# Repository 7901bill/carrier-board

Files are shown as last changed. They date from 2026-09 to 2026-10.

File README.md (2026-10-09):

# Carrier Board — Read This First

## Current PCB finishing work - 2026-10-09

Routing is substantially implemented in the saved PCB: all nine differential
pairs are defined and each member has top-layer tracks. Finish corner GND
vias, revise the board outline, and add/re-pour the required polygon copper.
Then refresh connectivity and resolve remaining DRC items in Altium. Final
routing, impedance, and release sign-off remain open.

The read-only saved-file audit found 85 connection records (83 GND and two
`NetCN1_78`), a broadly scoped 90-ohm differential rule, and unequal USB
track-only lengths. No DRC report was found, so a small remaining violation
count is not independently confirmed. See the [PCB audit](Documentation/PCB-Audit-2026-10-09.md) for evidence
and the limits of this inspection.

See the [current design status](Documentation/documentation.md) and
[subsystem dashboard](Documentation/Schematic-Subsystems/README.md).

## Earlier schematic-review findings requiring final re-verification

Both Amphenol `10164227-1001A1RLF` schematic instances now contain 100 unique
pin designators numbered `1–100`, matching their physical footprint pads.
`CN1` represents CM5 logical pins 1–100 and `CN2` represents logical pins
101–200; the unique component designators distinguish their identical pad
numbers.

The earlier warning that CN1 pins `3–6`, `9–12`, and `15–20` were grounds was
incorrect. Those are Ethernet, fan, LED, sync, and EEPROM-control signals.
Unused signals remain open; only pins identified as GND by the CM5 datasheet
are grounded.

The [current design status](Documentation/documentation.md) records all 43
schematic components in the saved LiveBOM and PCB, with their footprint names
matching. The earlier 2026-09-19 saved-CAD review found
incorrect camera-LDO pin assignments, disconnected Hailo output capacitors,
and USB ground contacts. The camera-LDO mapping remains incorrect in the
2026-09-24 ECO. Recovery switch `SW` has since been added and ECO-connected,
but its physical operation remains unverified. A clean compile is not
electrical sign-off.

At the 2026-09-29 documentation checkpoint, PCB layout setup had an
approximately 100 mm x 60 mm working outline,
all 43 components placed, a four-layer `SIG 1`/`GND`/`PWR`/`SIG 2` stack, and
basic clearance/width/via rules. That review listed open schematic,
mechanical, differential-pair, and net-name checks. Do not assume those older
items are closed merely because routing has started; re-verify affected nets
and rules before final sign-off.

## Documentation workflow

- [`Documentation/Journal.md`](Documentation/Journal.md) is the source of
  truth for verified decisions, evidence, and completed work.
- [`Documentation/documentation.md`](Documentation/documentation.md) is the
  daily progress record, active-blocker list, and resume checkpoint.
- [`Documentation/Schematic-Subsystems/`](Documentation/Schematic-Subsystems/README.md)
  contains the detailed implementation and verification status for each
  schematic block.

Whenever Bill asks to **update the documentation**, synchronize all three
layers in the same documentation pass:

1. Record verified facts and decisions in `Journal.md`.
2. Update the current progress, blockers, reminders, and daily changes in
   `documentation.md`.
3. Update the affected subsystem files and the subsystem progress dashboard.

Resolve contradictory current-status statements during that pass. Preserve
dated history, but clearly mark any older conclusion that a newer verified
entry supersedes.

Do **not** release or fabricate until PCB placement/routing and final DRC,
mechanical, BOM, and CPL reviews are complete.

Review the current design status, project journal, and affected subsystem
records before continuing.

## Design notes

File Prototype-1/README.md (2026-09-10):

# Wireless-Watchdog
Real-time animal spotting with YOLOv8n and at 433 MHz.

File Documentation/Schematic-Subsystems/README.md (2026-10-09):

# Schematic Subsystems

Last updated: 2026-10-09

This folder is the detailed working record for Schematic V1 of the Wireless
Watchdog CM5 carrier board. Each file covers one independently reviewable
subsystem. `Documentation/Journal.md` is the source of truth for verified
decisions, while `Documentation/documentation.md` is the daily working summary
and active-blocker list.

## Current PCB finishing work - 2026-10-09

Routing is substantially implemented in the saved PCB: all nine differential
pairs are defined and each member has top-layer tracks. Finish corner GND
vias, revise the board outline, and add/re-pour the required polygon copper.
Then refresh connectivity and resolve remaining DRC items in Altium. Final
routing, impedance, and release sign-off remain open.

The read-only saved-file audit found 85 connection records (83 GND and two
`NetCN1_78`), a broadly scoped 90-ohm differential rule, and unequal USB
track-only lengths. No DRC report was found, so a small remaining violation
count is not independently confirmed. See the [PCB audit](../PCB-Audit-2026-10-09.md) for evidence
and the limits of this inspection.

## Earlier schematic review findings

These are historical findings pending final re-verification, rather than a
new electrical audit. The October 9 PCB audit confirms routing progress but
does not close the earlier electrical or mechanical review items.

Schematic V1 completion is reopened. PCB import and a clean compile were
reported, but the saved-CAD review found electrical omissions and incorrect
LDO pin mapping. Re-verify affected items before release. The
[current design status](../documentation.md) contains the consolidated open
findings; the subsystem records below contain the supporting implementation
details.

## Progress dashboard

| File | Subsystem | Draft status | Principal remaining work |
|---|---|---|---|
| [01](01-power-input-usb-pd.md) | USB-C power input and PD | Validation open | Source/fuse budget; proposed Basic R1 |
| [02](02-main-5v-power.md) | Main 5 V supply | Validation open; placed | Reconcile main-rail/plane name; verify routed converter loop; peak-power review |
| [03](03-hailo-power-sequencing.md) | Hailo power and sequencing | Correction required; placed | Recheck C8/C9; verify routed buck loop; validate reset timing |
| [04](04-camera-power.md) | Camera power | Critical correction | Fix U3 pin mapping; add output capacitor; thermal review |
| [05](05-cm5-connectors.md) | CM5 connectors | **Component/footprint verified; placed; routing substantially implemented** | Preserve verified 10164227-1001A1RLF parts; finish board-level alignment, access, and fit checks |
| [06](06-m2-hailo-pcie.md) | M.2 Hailo/PCIe | **High priority release blocker; placed** | Resolve CN3 identity; verify three routed pairs and rule/profile scopes |
| [07](07-csi2-camera.md) | CSI-2 camera | Power dependency open; placed | Correct camera supply; verify FPC orientation; verify five routed pairs and 100-ohm rule scope |
| [08](08-programming-usb.md) | Programming USB | Correction required; placed | Recheck grounds; add ESD; verify routed USB pair, rule scope, and skew; review VBUS |
| [09](09-boot-recovery-reset.md) | Boot and recovery | SW placed and ECO-connected | Validate footprint and test point; accessible placement/routing; recovery test |
| [10](10-debug-uart.md) | Debug UART | Schematic complete | Place accessible connector and label pin order |
| [11](11-status-test-points.md) | Status and test access | Rough draft | Select final indicators and test points |

## Locked high-speed routing requirements

The current official CM5 datasheet establishes two controlled-impedance
classes for the nine routed differential pairs:

- 90 ohms differential: PCIe TX, PCIe RX, PCIe reference clock, and
  programming USB 2.0 D+/D-.
- 100 ohms differential: MIPI0 data lanes 0-3 and MIPI0 clock.

The earlier 85-ohm PCIe project note is superseded. Actual widths and gaps
have reportedly been calculated from the configured stackup, but they still
require JLCPCB confirmation. The October 9 audit confirms all nine pair objects. The highest-priority
`USB_DiffPair` rule is profile-driven at 90 ohms but scoped to `All`; confirm
and correct its effective scope, particularly for the 100-ohm MIPI pairs.
The lower-priority generic rule remains a placeholder.

## Historical PCB layout setup

The bullets below record the September setup. The current saved plane net
assignments are GND and `5V`; see the October 9 audit for current evidence.

- Working outline: approximately 100 mm x 60 mm; all 43 components are placed
  top-side and inside it. Mechanical fit and connector/retention checks remain.
- Stack: L1 `SIG 1`, L2 solid `GND`, L3 `PWR` intended as the main 5 V plane,
  and L4 `SIG 2`.
- General rules: 0.15 mm clearance, 0.20 mm minimum/0.25 mm preferred width,
  and 0.60 mm/0.30 mm through vias. Resolve the external note's 1.0 mm maximum
  versus the saved rule's 0.50 mm maximum.
- Keep CSI, PCIe, and USB on L1 over continuous L2 ground where practical.
  Avoid L4 for these pairs because its adjacent reference is the power plane.
- The reported PCB rail rename to `5V` is not present in the current saved net
  table, which still uses `NetC2_1`; reconcile it with schematic/documentation
  names before the next ECO.

## Working order

1. Add corner GND vias and revise the board shape.
2. Add/re-pour polygon copper and review ground continuity and islands.
3. Refresh connectivity; inspect saved GND and `NetCN1_78` connections.
4. Verify differential profile/rule scopes and USB length/skew.
5. Resolve remaining DRC items and run final DRC after all layout changes.
6. Re-verify historical electrical/mechanical findings and complete final
   silkscreen, ERC/ECO, BOM/CPL, fabrication, and drill-output reviews.

## Status vocabulary

- **Confirmed:** explicitly locked in the current project documentation.
- **Planned:** required work whose exact implementation may still need review.
- **Open:** requires a design choice or external verification.
- **Done:** implemented in CAD and subsequently verified.

## Session rule

After work on a subsystem, update its status, completed work, open questions,
and session notes. Record verified material decisions in
`Documentation/Journal.md` and keep the active summary in
`Documentation/documentation.md` synchronized.

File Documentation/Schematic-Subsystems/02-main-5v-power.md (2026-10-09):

# 02 — Main 5 V Power Supply

Last updated: 2026-10-09

## Saved PCB checkpoint - 2026-10-09

The saved October 8 PCB independently confirms substantial routing and all
nine differential-pair definitions, superseding the earlier no-pair/no-routing
snapshot below. Finish corner GND vias, the board outline, polygon pours,
connectivity checks, and final DRC. Differential-rule scope and USB skew need
review. This checkpoint does not close older electrical or mechanical findings.
See the [PCB audit](../PCB-Audit-2026-10-09.md) for current evidence.

## Open review actions — 2026-09-19

- Open: the 6.5 A converter rating is not the available system budget.
  A 5 V/6.5 A load is 32.5 W, exceeding the 27 W input before losses.
  Close peak/continuous load and fuse/thermal margins with subsystem 01.
- Proposed only: C4 `C466768` → Basic `C14663` (already C3/C7):
  100 nF, X7R, ±10%, 0603; voltage rating increases from 25 V to 50 V.
- Optional clarity improvement: label main 5 V (`NetC2_1`), Hailo output
  (`NetC11_2`) and camera output (`NetCN4_22`) with their intended rail names.

These actions are not implemented. Current release blockers are consolidated
in the [main design status](../documentation.md).

## Subsystem purpose

Convert the negotiated 9 V input into the shared `5V_MAIN` rail used by the
CM5 and the local Hailo and camera regulators.

## Earlier status snapshot

**Schematic complete and transferred to PCB.** The converter and target rail
are confirmed. Peak-load, transient, efficiency, and thermal verification
remain prototype-validation tasks.

**Historical PCB layout setup:** U5 and its passives are placed. The layout note reports
that L3 is a continuous main-5-V plane and that the PCB net was renamed to
`5V`, but the current saved PCB net table still shows `NetC2_1`; the schematic
and documentation use `5V_MAIN`/`5V_6.5A`. Verify the actual L3 assignment and
choose an ECO-stable authoritative rail name before routing. Route the MP2329
input capacitors, switching loop, inductor, output capacitors, and feedback
network before ordinary signals. The configured generic width rule is not a
power-current rule; derive suitable copper widths/plane connections from the
final current and thermal budget.

## Confirmed design

- Converter: MPS `MP2329GG-Z`, LCSC `C5349327`.
- Input: negotiated 9 V from the USB-PD input section.
- Output: `5V_MAIN`.
- The device is rated for 6.5 A continuous and 7.5 A peak, subject to the
  complete design and thermal conditions.
- Recorded datasheet starting values for 5 V are:
  - upper feedback resistor: 40.2 kΩ, `C12447`;
  - lower feedback resistor: 5.49 kΩ, `C54102278`;
  - feed-forward capacitor: 33 pF, `C48543706`;
  - inductor: 3.3 µH, `C19268654` (`CYA1250-3.3UH`, 20 A rated,
    32 A saturation). This stocked replacement supersedes `C19268642`.
- The CAD sheet also uses 22 µF/25 V capacitors `C45783`, 220 nF/25 V
  capacitor `C21120`, and 100 nF/25 V capacitor `C466768` in the power section.
- MP2329 input qualification is implemented with 453 kΩ `C25818` and 100 kΩ
  `C25803`, targeting an approximately 7.5 V startup threshold.
- `5V_MAIN` directly supplies the CM5 and feeds separate local regulators for
  the Hailo and camera rails.

## Confirmed load facts

- The earlier approximately 13 W system estimate is based mainly on typical
  loading and is not sufficient by itself for final component ratings.
- The Hailo-8L alone can require as much as 6.6 W/2 A at 3.3 V.
- Final verification must consider simultaneous peak load, startup, conversion
  loss, thermal derating, charger capability, and cable capability.

## Planned schematic content

- Complete MP2329 reference circuit.
- Input/output ceramic capacitors with voltage and effective-capacitance margin.
- Feedback and feed-forward network.
- Inductor with suitable RMS and saturation-current ratings.
- Enable and startup behavior coordinated with the USB-PD section.
- `5V_MAIN`, input, switch-node, and ground test access where safe.
- Clear net connections to the CM5 and both local 3.3 V branches.

## Definition of done

- All component values are checked against the current MP2329 datasheet.
- A defensible worst-case power budget is recorded.
- Inductor and capacitors meet electrical and thermal margins.
- The expected startup state is defined for 5 V input and successful 9 V PD.
- Every CM5 5 V input is supplied as required by the CM5 reference design.

## References

- `Documentation/documentation.md`, Power architecture.
- `Documentation/Research MD/power-design-explainer.md`.
- MP2329 datasheet in `Documentation/Datasheets/`.

## Session notes

- 2026-09-18: Initial subsystem draft created from confirmed project records.
- 2026-09-19: Replaced unavailable `C19268642` with stocked `C19268654` and
  imported its dedicated footprint into the PCB project.
- 2026-09-28: Recorded that placement and the four-layer layout setup are
  complete, but the reported `5V` plane/net rename is not reflected in the
  current saved net table. Main-converter loop routing is the first routing
  priority after the open schematic corrections and net/plane verification.

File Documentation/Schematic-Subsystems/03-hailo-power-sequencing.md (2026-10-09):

# 03 — Hailo Power and Reset Sequencing

Last updated: 2026-10-09

## Saved PCB checkpoint - 2026-10-09

The saved October 8 PCB independently confirms substantial routing and all
nine differential-pair definitions, superseding the earlier no-pair/no-routing
snapshot below. Finish corner GND vias, the board outline, polygon pours,
connectivity checks, and final DRC. Differential-rule scope and USB skew need
review. This checkpoint does not close older electrical or mechanical findings.
See the [PCB audit](../PCB-Audit-2026-10-09.md) for current evidence.

## Purpose

Generate the dedicated Hailo-8L 3.3 V rail and ensure that the module remains
in reset until its supply is stable.

## Earlier status snapshot

**Correction required.** The Hailo rail reaches all five M.2 power contacts,
but C8-1 and C9-1 have no PCB net; only their ground pads are connected.
Connect their electrical pin ends to the output (`NetC11_2`), regenerate ECO,
and verify both pads explicitly. Check capacitor tolerance/DC-bias losses.
The TPS54302 is now `U1` (formerly `U3`); its EN pin 5 may float per TI, so
that is not an error. The [main design status](../documentation.md) tracks the
remaining release checks.
Earlier completion notes are superseded; no correction has yet been applied.
The 2026-09-28 inventory audit did not recheck the C8/C9 pad nets, so verify
their current state directly in Altium before closing this item.

## Confirmed design

- Regulator: TI `TPS54302DDCR`, LCSC `C311983`.
- Input: `5V_MAIN`.
- Output: `3V3_HAILO`.
- The Hailo-8L maximum documented load is 2 A at 3.3 V/6.6 W.
- Raw 5 V must never be connected to the Hailo M.2 power contacts.
- The Hailo rail is separate from the camera 3.3 V rail.
- The TPS54302 is an adjustable 3 A, 400 kHz synchronous buck with internal
  soft-start but no power-good output.
- Datasheet starting values recorded by the project are:
  - 100 kΩ from output to FB;
  - 22.1 kΩ from FB to ground;
  - 47 pF across the upper feedback resistor;
  - 6.8 µH inductor;
  - at least 10 µF ceramic input decoupling;
  - 0.1 µF from BOOT to SW;
  - 44 µF effective ceramic output capacitance.
- The inductor must support at least 3 A RMS and preferably more than 4 A
  saturation current.
- Final selected passives are:
  - 6.8 µH molded inductor `C7461350`, 3.5 A rated and 5 A saturation;
  - 100 kΩ upper feedback resistor `C25803`;
  - 22.1 kΩ lower feedback resistor `C723484`;
  - 47 pF C0G feed-forward capacitor `C1671`;
  - two 22 µF output capacitors `C45783`;
  - 100 nF bootstrap capacitor `C14663`.
- `3V3_HAILO` must be stable before M.2 `PERST#` is released.

## Implemented content and open correction

- TPS54302 and selected passives are placed, but output capacitors C8/C9
  require connection before the supply can be considered complete.
- Regulator enable and CM5-controlled reset connections; no separate load
  switch.
- Connection to all five M.2 power contacts.
- After C8/C9 and the rail-net state are corrected and ECO-verified, route the
  TPS54302 input/boot/switch/inductor/output loops and local decoupling before
  ordinary signals. Keep the switch node and inductor away from the PCIe pairs.

## Verification remaining

- Confirm useful test access for `5V_MAIN`, `3V3_HAILO`, reset, and ground.
- Review direct CN2-9 to CN3-50 PERST# behavior with no supply-good gating;
  establish startup and brownout/restart timing before closing sequencing.
- Compile and run ERC after the remaining schematic subsystems are complete.
- Measure startup and confirm `PCIe_nRST` remains asserted until
  `3V3_HAILO` is stable.
- Verify ripple, load transient response, inductor temperature, and effective
  ceramic capacitance on the prototype.

## Load-switch decision

- **Omitted from Rev A:** `TPS22965`, LCSC `C347592`.
- TPS22965 is a load switch, not a step-down regulator. It would only add
  independent rail isolation, slew control, or power cycling.
- `TPS54302DDCR` (`C311983`) remains the required 5 V-to-3.3 V buck regulator.
- Rev A relies on the TPS54302's 5 ms soft-start and the CM5-controlled
  `PCIe_nRST`/M.2 `PERST#` connection. Their relative timing will be measured
  during bring-up.

## Definition of done

- The regulator is fully drawn and configured for 3.3 V.
- All five M.2 power contacts receive `3V3_HAILO`.
- Input/output capacitance is verified at operating bias.
- Inductor current and thermal margins are verified.
- The sequencing circuit provides a documented guarantee that power is stable
  before reset release.
- Enable, reset, and rail behavior can be measured during bring-up.

## References

- `Documentation/Research MD/power-design-explainer.md`.
- `Documentation/Research MD/PCIe-x1-Differential-Pairs-Explainer.md`.
- TPS54302 and Hailo-8L datasheets.

## Session notes

- 2026-09-18: Initial subsystem draft created from confirmed project records.
- 2026-09-19: Completed the sourced TPS54302 circuit and all M.2 power
  connections; reset-timing and prototype validation remain open.
- 2026-09-28: Components are placed and power-loop routing is next, but C8/C9
  must be corrected and verified first. No routing completion is claimed.

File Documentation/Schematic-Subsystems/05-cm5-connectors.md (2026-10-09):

# 05 — CM5 Connectors and Base Connections

Last updated: 2026-10-09

## Saved PCB checkpoint - 2026-10-09

The saved October 8 PCB independently confirms substantial routing and all
nine differential-pair definitions, superseding the earlier no-pair/no-routing
snapshot below. Finish corner GND vias, the board outline, polygon pours,
connectivity checks, and final DRC. Differential-rule scope and USB skew need
review. This checkpoint does not close older electrical or mechanical findings.
See the [PCB audit](../PCB-Audit-2026-10-09.md) for current evidence.

## Purpose

Provide the complete electrical and mechanical interface between the CM5 and
the carrier-board power, PCIe, camera, programming, recovery, and debug
subsystems.

## Earlier status snapshot

**Connector component verified and approved for placement and routing.** `CN1`
and `CN2` use the exact Raspberry Pi-specified Amphenol
`10164227-1001A1RLF` (`C6782225`). Both symbols have 100 unique physical pin
designators `1–100`, and both use the verified manufacturer-matching footprint
`CONN-SMD_100P-P0.40_10164227-1001A1RLF`. No symbol, footprint, or component
replacement is required.

The two placed connector instances are ready to route. Preserve the user's
chosen visible pin names and the verified physical numbering/electrical types.
The 2026-09-23 PCB ECO connects CN1-93 to recovery switch `SW`, which is
grounded on its other terminal. Access, test point, and functional recovery
remain open in [09](09-boot-recovery-reset.md).
Programming USB ground/protection and camera/Hailo supply corrections are
tracked in the [main design status](../documentation.md).
The reported clean compile/ECO does not close those unrelated subsystem
issues. Final board-level CM5 alignment, clearance, and 1:1 assembly fit remain
placement checks, not reasons to change the verified connector component.

## Confirmed design

- The design uses a CM5, not a CM4; their pin assignments are not interchangeable.
- The two carrier connectors are Amphenol `10164227-1001A1RLF` 100-pin parts.
- The exact component identity, schematic pin count, pad numbering, footprint
  association, and copper land geometry were independently verified on
  2026-09-29. The footprint has 100 SMT pads, 0.40 mm pitch, 0.20 mm x 0.70 mm
  lands, 19.60 mm end-to-end contact span, and 3.08 mm row-center spacing,
  matching the Amphenol recommended PCB layout.
- The `-1001A1RLF` variant is the no-hold-down, 1.5 mm mated-stack-height
  receptacle specified for the standard low-profile CM5 installation.
- Connector 1 uses CM5 logical pins 1–100.
- Both schematic symbols and both footprints use physical pin numbers 1–100.
  `CN1` represents CM5 logical pins 1–100; `CN2` represents logical pins
  101–200. Their unique component designators distinguish the two instances.
- CN1 pins 3–6 and 9–12 are Ethernet pairs, not grounds. Pins 15–20 are
  Ethernet/fan/EEPROM-control signals, not grounds. They remain unused in
  Rev A except where later requirements explicitly say otherwise.
- All 21 CN1 ground pins and all 30 CN2 ground pins were checked as connected.
- Unused GPIOs are explicitly disconnected. Pins 51/55 are reserved for UART,
  and pins 97/100 are used for camera control.
- Pins 56/58 (`GPIO3/SCL1`, `GPIO2/SDA1`) are unused; camera control instead
  uses pins 80/82 (`SCL0`, `SDA0`).
- Pins 21 `LED_nACT`, 76 `VBAT`, 92 `PWR_BUT`, 95 `LED_nPWR`, and 99
  `PMIC_ENABLE` are unused in Rev A and have no-connect markers. Pin 93
  `nRPIBOOT` remains reserved for the recovery circuit.
- CM5 pin 78 `GPIO_VREF` connects to the CM5 3.3 V output net from pins 84 and
  86 to select 3.3 V GPIO signaling.
- CM5 pin 55 `GPIO14/UART0_TX` is the debug transmit signal.
- CM5 pin 51 `GPIO15/UART0_RX` is the debug receive signal.
- CM5 pin 93 `nRPIBOOT` is used for USB recovery control.
- CM5 pins 94 and 96 (`CC1` and `CC2`) remain intentionally unconnected in
  this design; neither board USB-C connector uses them.
- CM5 pin 80 `SCL0` and pin 82 `SDA0` are assigned to camera control.
- CM5 pin 97 `CAM_GPIO0` and pin 100 `CAM_GPIO1` are assigned to camera control.
- CM5 MIPI0 mapping is verified as pins 115/117 for data lane 0, 121/123 for
  lane 1, 127/129 for clock, 133/135 for lane 2, and 139/141 for lane 3.
- CM5 pin 141 is `MIPI0_D3_P`; it is not camera lane 0 negative.
- The full CM5 variant has eMMC and does not require a microSD connector.

## Planned schematic content

- Every required CM5 5 V and ground contact.
- Complete PCIe lane, reference clock, reset, and clock-request connections.
- Complete CSI-2, camera I²C, and camera-control connections.
- USB 2.0 programming/recovery signals.
- `nRPIBOOT`, reset/power control, and UART.
- Explicit no-connect markers for every intentionally unused pin.
- Clear cross-sheet net labels with consistent spelling.

## Remaining board-level checks

1. Both connectors are placed; confirm final CM5 mechanical alignment,
   orientation, retention, installed-module clearance, and 1:1 assembly fit.
   This is a placement/system check; the component and footprint are approved.
2. Confirm connector-edge, camera-cable, antenna, heatsink, and access
   constraints within the approximately 100 mm x 60 mm working outline.
3. Re-run PCB DRC after routing and every relevant ECO. Watch for recurrence of
   the stale/corrupt placed-footprint DRC behavior reported during placement.

## Definition of done

- Both connector symbols and footprints are independently verified. Complete
  as of 2026-09-29; do not replace or redraw them without a new approved part.
- Every required power and ground pin is connected.
- Every used interface reaches its corresponding subsystem.
- Every intentionally unused pin has a no-connect marker.
- No CM4 pin assumptions are present.
- A later compile/ECO produces no unexplained connector mismatch.

## References

- Root `README.md` release warning.
- `Documentation/Research MD/CM5-Connector-Wiring-and-Bringup.md`.
- Current CM5 datasheet and official CM5 IO reference design.
- Amphenol connector drawing.

## Session notes

- 2026-09-18: Initial subsystem draft created; connector corrections remain
  the first schematic priority.
- 2026-09-19: Consolidated the connector sheets, connected the complete M.2
  and CSI interfaces, and corrected the imported symbol's displayed camera
  lane labels.
- 2026-09-19: Corrected CN2 to physical pin designators 1–100 and verified both
  placed connectors have 100 unique pins. Confirmed all required grounds are
  grounded and unused GPIOs are disconnected. Corrected the earlier false
  classification of Ethernet/control pins as grounds.
- 2026-09-19: Completed remaining wiring/no-connect treatment, obtained a
  clean compile/ECO with no reported errors or warnings, and transferred all
  components to the PCB document. Component placement is next.
- 2026-09-28: All components, including CN1 and CN2, are placed inside the
  working outline. Placement does not close alignment, retention, clearance,
  footprint, or full mechanical-fit verification.
- 2026-09-29: Closed component and footprint verification for CN1/CN2. Both
  instances are confirmed as Amphenol `10164227-1001A1RLF` / LCSC `C6782225`;
  each symbol has 100 unique pins and each linked footprint matches the
  manufacturer's 100-pad land pattern. No connector-library change is needed.
  The placed instances are approved for routing, subject only to the remaining
  board-level alignment, clearance, and final fit checks above.

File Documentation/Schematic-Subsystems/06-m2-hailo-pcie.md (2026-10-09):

# 06 — Hailo-8L M.2 and PCIe

Last updated: 2026-10-09

## Saved PCB checkpoint - 2026-10-09

The saved October 8 PCB independently confirms substantial routing and all
nine differential-pair definitions, superseding the earlier no-pair/no-routing
snapshot below. Finish corner GND vias, the board outline, polygon pours,
connectivity checks, and final DRC. Differential-rule scope and USB skew need
review. This checkpoint does not close older electrical or mechanical findings.
See the [PCB audit](../PCB-Audit-2026-10-09.md) for current evidence.

## Open review actions — 2026-09-24

- **HIGH PRIORITY - CN3 release blocker. Resolve before PCB fabrication or
  connector procurement.** The selected schematic and BoM DesignItemId is
  UMAX `91302-42-067RDM` (LCSC `C601195`), while the placed PCB footprint
  and embedded STEP model are named for `91302-32-067RDM`. The supplier lists
  the selected `-42-` variant at 4.2 mm and the `-32-` variant at 3.2 mm.
  These are distinct orderable parts. Their name difference does not prove a
  copper land-pattern mismatch, but unverified mating height, locating posts,
  or standoff geometry could prevent the Hailo module from seating and force
  a board rework or respin.
  Compare manufacturer drawings for both variants: contact and mounting pad
  layout, locating posts, board edge, card mating plane, module standoff, and
  nearby clearance. Record the drawing revisions and verified intended part.
  If `-42-` is intended, use or validate a `-42-` footprint and 3D model; if
  `-32-` is intended, correct the schematic part identity and supplier code.
  Refresh the BoM, transfer the change to the PCB, and confirm that CAD and
  purchasing identifiers agree. Do not close this item on matching names alone.
- The latest 2026-09-28 LiveBOM save now agrees with the schematic on CN3's
  Comment, `Name=C601195`, `Source=LCSC`, and selected part. This resolves
  the earlier saved-parameter discrepancy; the `-42-` part versus `-32-`
  footprint/3D mechanical review remains open. See the consolidated
  [main design status](../documentation.md).
- Power dependency: fix disconnected C8/C9 in [03](03-hailo-power-sequencing.md).
  Direct PERST# has no supply-good gating; startup/brownout timing is open.
- Confirm stackup/impedance rules and module mounting before routing.

These actions are not implemented. Current release blockers are consolidated
in the [main design status](../documentation.md).

## Subsystem purpose

Connect the Hailo-8L module to the CM5 over PCIe Gen 2 x1 and provide its
power, clock, reset, and ground connections.

## Earlier status snapshot

**Schematic wiring complete.** The M.2 power, ground, PCIe lane 0, reference
clock, reset, and clock-request signals are connected to the CM5 connector.
Unused lane, wake, configuration, and remaining contacts are intentionally
left unconnected. PCB differential-pair rules, routing, and length tuning
remain layout-phase work.

**Historical PCB layout setup:** CN2 and CN3 are placed, and the configured stack places
L1 over a continuous L2 ground reference. The layout note reports the 90-ohm
profile calculation complete, but the saved PCB still has no PCIe pair objects
or populated PCIe pair class, and its differential routing rule remains the
generic 15 mil/10 mil placeholder. Create the three pair objects, populate the
PCIe class, link its rule to the 90-ohm profile, and verify the geometry with
JLCPCB before routing on L1. The CN3 part/footprint/STEP identity blocker still
must be resolved before placement is considered mechanically final.

## Confirmed parts and architecture

- Socket: UMAX `91302-42-067RDM`, LCSC `C601195`.
- The socket is a 67-contact M-key socket and accepts the Hailo-8L B+M module.
- Link: PCIe Gen 2 x1 from the CM5.
- Only PCIe lane 0 is used; lane 1 receives explicit no-connect markers.
- The M.2 module includes transmit-side AC-coupling capacitors; the carrier
  must not add a duplicate set without a reviewed reason.

## Confirmed power and ground mapping

- `3V3_HAILO`: M.2 pins 2, 4, 70, 72, and 74.
- Ground: pins 3, 27, 33, 39, 45, 51, 57, 71, and 73.
- All listed power and ground contacts must be connected.

## Confirmed PCIe mapping

| M.2 pin/signal | CM5 pin/signal |
|---|---|
| 41 `PETn0` | 118 `PCIe_RX_N` |
| 43 `PETp0` | 116 `PCIe_RX_P` |
| 47 `PERn0` | 124 `PCIe_TX_N` |
| 49 `PERp0` | 122 `PCIe_TX_P` |
| 53 `REFCLKn` | 112 `PCIe_CLK_N` |
| 55 `REFCLKp` | 110 `PCIe_CLK_P` |
| 50 `PERST#` | 109 `PCIe_nRST` |
| 52 `CLKREQ#` | 102 `PCIe_CLK_nREQ` |

The endpoint's transmit signals connect to the host's receive signals, and the
endpoint's receive signals connect to the host's transmit signals.

## Confirmed no-connect intent

- Lane 1 pins 29, 31, 35, and 37 are unused.
- Configuration contacts 1, 21, and 75 are module-grounded detection bits and
  remain open unless detection is implemented; pin 69 is NC on the module.
- The complete unused-pin list is maintained in
  `Documentation/Research MD/PCIe-x1-Differential-Pairs-Explainer.md`.
- M.2 pin 54 `PEWAKE#` and CM5 pin 104 `PCIE_nWAKE` are unused in Rev A.
- CM5 pin 106 `PCIE_PWR_EN` is unused because Rev A uses an always-on
  `3V3_HAILO` regulator and omits the external PCIe load switch.

## Completed schematic content

- All confirmed PCIe, clock, reset, power, and ground connections.
- Explicit no-connect markers on every unused electrical contact.
- Local bulk and high-frequency M.2 decoupling.
- Net-label continuity between the M.2 sheet and CM5 connector sheet.

## PCB-layout work remaining

- Define `PCIe_TX_P/N`, `PCIe_RX_P/N`, and `PCIe_CLK_P/N` as differential
  pairs.
- Route all three pairs at 90 ohms differential, as specified by the current
  official CM5 datasheet. This supersedes the older 85-ohm project note. The
  Hailo module datasheet does not state a conflicting value and instead refers
  the interface to the PCIe M.2 specification.
- Derive the actual width and gap for 90 ohms from the final JLCPCB stackup; do
  not use the PCB document's generic 15 mil/10 mil placeholder geometry.
- Route each pair over continuous ground and tune P/N skew within each pair.
- Keep the pairs away from the TPS54302 switch node and inductor.
- Verify useful rail, reset, clock-request, and ground test access without
  adding stubs to high-speed pairs.
- Do not add external parallel termination across the pairs. CM5 already has
  AC-coupling capacitors on its PCIe transmitter, and the M.2 module provides
  transmitter-side coupling for the opposite direction; do not duplicate
  those capacitors without a reviewed device-specific reason.

## Definition of done

- Pin mapping is checked against the Hailo module datasheet and CM5 datasheet.
- Polarity and TX/RX direction are reviewed independently.
- Power, ground, clock, and control connections are complete.
- All unused contacts are explicitly marked.
- The extra library pin is identified and documented.
- CN3's selected MPN, supplier code, PCB land pattern, 3D model, card seating
  height, and module standoff are checked against manufacturer drawings; the
  refreshed BoM and PCB agree on the verified variant.
- Reset release is coordinated with `3V3_HAILO` stability.

## References

- `Documentation/Research MD/PCIe-x1-Differential-Pairs-Explainer.md`.
- Hailo-8L M.2 Key B+M ET Module Data Sheet Rev. 4.0.
- CM5 datasheet and Raspberry Pi M.2 HAT+ reference schematic.
- [Selected `-42-` connector, C601195](https://jlcpcb.com/partdetail/UMAX-91302_42067RDM/C601195)
  and [`-32-` connector, C1509730](https://item.szlcsc.com/1600530.html);
  use their manufacturer drawings for the compatibility decision.

## Session notes

- 2026-09-18: Initial subsystem draft created from the locked pin table.
- 2026-09-19: M.2-to-CM5 schematic wiring completed. Confirmed that pin 41
  `PETn0` connects to CM5 `PCIe_RX_N` pin 118 and pin 43 `PETp0` connects to
  `PCIe_RX_P` pin 116; pin 42 is not part of the lane-0 connection.
- 2026-09-24: Raised the CN3 `-42-` purchasing part versus `-32-` PCB
  footprint/STEP identity to a high-priority release blocker. Mechanical and
  land-pattern compatibility remain unverified; no CAD change was made.
- 2026-09-28: Verified the current CM5 routing guidance and locked all three
  used PCIe pairs, including reference clock, to 90 ohms differential. This
  supersedes the earlier 85-ohm note. Pair creation, stackup geometry, routing,
  and tuning remain PCB work; no CAD change was made.
- 2026-09-28: Layout setup subsequently placed CN2/CN3 and reportedly
  calculated the 90-ohm profile. Saved-CAD review still found zero pair
  objects and the generic unlinked rule, so pair/class/rule completion remains
  open before routing.

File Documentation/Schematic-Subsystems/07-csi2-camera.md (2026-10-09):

# 07 — CSI-2 Camera Interface

Last updated: 2026-10-09

## Saved PCB checkpoint - 2026-10-09

The saved October 8 PCB independently confirms substantial routing and all
nine differential-pair definitions, superseding the earlier no-pair/no-routing
snapshot below. Finish corner GND vias, the board outline, polygon pours,
connectivity checks, and final DRC. Differential-rule scope and USB skew need
review. This checkpoint does not close older electrical or mechanical findings.
See the [PCB audit](../PCB-Audit-2026-10-09.md) for current evidence.

## Open review actions — 2026-09-19

- Camera power is not complete: fix U3 pin mapping and add its output
  capacitor as tracked in [04](04-camera-power.md).
- Confirm the selected Camera Module 3 current requirement, FPC contact
  orientation, module clearances, and stackup/impedance rules before routing.

These actions are not implemented. Current release blockers are consolidated
in the [main design status](../documentation.md).

## Subsystem purpose

Connect a Raspberry Pi camera module to the CM5 using the 22-pin FPC interface,
including video lanes, control, power, and grounds.

## Earlier status snapshot

**Incomplete; signal wiring is drawn.** All four MIPI data lanes, MIPI clock,
camera I²C, both camera GPIO controls, `3V3_CAMERA`, and ground contacts are
drawn between the 22-pin FPC connector and the CM5 connector symbols. U3 is
wired incorrectly and lacks its output capacitor. Cable orientation, connector
pad 1, module clearance, PCB differential-pair rules, routing, and functional
operation remain unverified.

**Historical PCB layout setup:** CN2 and CN4 are placed, and the intended MIPI routes are
on L1 over continuous L2 ground. The layout note reports that the 100-ohm
profile and a CSI differential-pair class were created, but the current saved
PCB still contains zero pair objects and no saved CSI class membership; the
differential rule remains the generic 15 mil/10 mil placeholder. Define all
five pairs, populate the CSI class, link its rule to the 100-ohm profile, and
verify the calculated geometry with JLCPCB before routing. Camera power and
FPC/cable orientation must still be corrected or verified first.

## Confirmed design basis

- Camera: standard Raspberry Pi Camera Module 3 using the IMX708 sensor (not
  Camera Module 3 Wide).
- The carrier uses the same 22-contact, 0.5 mm-pitch style used for the
  Raspberry Pi 5 camera/display interface.
- Current carrier connector: Hirose `FH55-22S-0.5SH`, LCSC `C5182313`, a
  22-position, 0.5 mm-pitch, bottom-contact front-flip FPC connector.
- The normal Raspberry Pi 5 camera cable adapts the Pi 5-style 22-pin end to
  the standard Camera Module 3 connector.
- Camera video uses CSI-2 differential data and clock pairs.
- Camera configuration uses the CM5 camera I²C bus, not the CSI-2 data lanes.
- CM5 pin 80 `SCL0` maps to `CAM_I2C_SCL`.
- CM5 pin 82 `SDA0` maps to `CAM_I2C_SDA`.
- CM5 pin 97 `CAM_GPIO0` and pin 100 `CAM_GPIO1` provide camera controls.
- Camera connector power is `3V3_CAMERA` on pin 22.
- A separate 1.8 V carrier rail is not required for Camera Module 3.
- The current CM5 documentation states that SCL0/SDA0 have internal 1.8 kΩ
  pull-ups to the CM5 3.3 V rail. Do not fit an additional pair by default.

## Confirmed connector mapping

| CSI pin/signal | CM5 pin/signal |
|---|---|
| 2 `CAM_D0_N` | 115 `MIPI0_D0_N` |
| 3 `CAM_D0_P` | 117 `MIPI0_D0_P` |
| 5 `CAM_D1_N` | 121 `MIPI0_D1_N` |
| 6 `CAM_D1_P` | 123 `MIPI0_D1_P` |
| 8 `CAM_CLK_N` | 127 `MIPI0_C_N` |
| 9 `CAM_CLK_P` | 129 `MIPI0_C_P` |
| 11 `CAM_D2_N` | 133 `MIPI0_D2_N` |
| 12 `CAM_D2_P` | 135 `MIPI0_D2_P` |
| 14 `CAM_D3_N` | 139 `MIPI0_D3_N` |
| 15 `CAM_D3_P` | 141 `MIPI0_D3_P` |
| 17 `CAM_IO0` | 97 `CAM_GPIO0` |
| 18 `CAM_IO1` | 100 `CAM_GPIO1` |
| 20 `CAM_I2C_SCL` | 80 `SCL0` |
| 21 `CAM_I2C_SDA` | 82 `SDA0` |
| 22 `3V3_CAMERA` | AP2112 output |

CSI contacts 1, 4, 7, 10, 13, 16, and 19 connect to ground. The standard
Camera Module 3 uses two data lanes through the normal 22-to-15-pin cable;
wiring lanes 2 and 3 preserves the standard four-lane 22-pin interface.

## Drawn schematic content — verification incomplete

- `C5182313` FPC connector; contact numbering and cable orientation still need
  verification against the connector and cable drawings.
- All required CSI-2 data and clock pairs.
- Camera I²C and control connections.
- Intended `3V3_CAMERA` and ground connections; camera power remains incomplete
  until U3 and its output capacitor are corrected and reverified.
- Explicit no-connect markers on unused contacts, if any.
- Power, control, and ground test-access requirements remain to be verified;
  do not add stubs to high-speed CSI-2 pairs.

## PCB-layout and review work remaining

- Verify FPC contact-side orientation and pad 1 against the `C5182313`
  connector drawing and the selected Raspberry Pi camera cable.
- Define all four data pairs plus the clock pair as PCB differential pairs.
- Route all five MIPI pairs at 100 ohms differential, as specified by the
  current official CM5 datasheet, and derive the actual width and gap from the
  final JLCPCB stackup. Route over continuous ground and tune P/N skew within
  each pair.
- The selected Hirose FH55 connector is an impedance-controlled high-speed
  GSSG connector whose catalog characterizes the connector/FPC path around
  90 ohms with a broad tolerance. That fixed connector characteristic does not
  replace the CM5 requirement: the carrier PCB traces remain 100 ohms
  differential. Verify the selected Raspberry Pi cable/contact orientation as
  part of the complete channel review.
- Keep test access off the MIPI pairs and verify connector-shell grounding.
- Do not add external parallel termination resistors across the MIPI pairs;
  the controlled impedance is established by the PCB geometry and the D-PHY
  endpoints handle interface termination.

## Definition of done

- The selected Camera Module 3, cable, and connector drawings agree on contact
  orientation.
- Lane count and every CSI-2 polarity are checked against authoritative sources.
- Camera power, grounds, I²C, and control signals are complete.
- Pull-up ownership is documented without duplicating the CM5 pull-ups.
- No high-speed signal is left ambiguous or mislabeled.

## References

- `Documentation/documentation.md`, current camera decisions.
- [Current CM5 datasheet](https://datasheets.raspberrypi.com/cm5/cm5-datasheet.pdf)
  and Camera Module 3 documentation.
- Official CM5 IO camera reference circuit.

## Session notes

- 2026-09-18: Initial subsystem draft created. Later confirmed pull-up guidance
  supersedes the older I²C explainer's external-pull-up recommendation.
- 2026-09-19: CSI-to-CM5 schematic wiring completed. Corrected the CM5 camera
  lane interpretation: CM5 pin 115 is `MIPI0_D0_N`; pin 141 is
  `MIPI0_D3_P`, not lane 0 negative. Updated the connector-library display
  labels accordingly.
- 2026-09-28: Locked the carrier routing target to 100 ohms differential for
  all four data pairs and the clock pair from the current CM5 datasheet.
  Recorded the FH55 connector's separate fixed impedance characterization so
  it is not mistaken for the PCB trace target. No CAD change was made.
- 2026-09-28: Layout setup placed CN2/CN4 and reportedly created the 100-ohm
  profile and CSI class. Saved-CAD inspection still found no pair objects or
  class members and only the generic differential rule, so setup is not yet
  routing-ready.

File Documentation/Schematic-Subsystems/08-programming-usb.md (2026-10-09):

# 08 — CM5 Programming USB

Last updated: 2026-10-09

## Saved PCB checkpoint - 2026-10-09

The saved October 8 PCB independently confirms substantial routing and all
nine differential-pair definitions, superseding the earlier no-pair/no-routing
snapshot below. Finish corner GND vias, the board outline, polygon pours,
connectivity checks, and final DRC. Differential-rule scope and USB skew need
review. This checkpoint does not close older electrical or mechanical findings.
See the [PCB audit](../PCB-Audit-2026-10-09.md) for current evidence.

## Purpose

Provide a dedicated USB 2.0 device connection from a development computer to
the CM5 for initial eMMC flashing and recovery.

## Earlier status snapshot

**Correction required.** The 2026-09-19 review found programming-port cable
ground-pad groups `A1B12` and `B1A12` without PCB nets. The current two
USB-C designators are `USBC 1` and `USBC2`, so first identify the programming
connector in the saved CAD and recheck its pad nets; grounded shell pads 1–4
do not replace signal ground. No USB data ESD array is present in the current
43-component inventory; select and implement suitable low-capacitance
protection before routing.

Duplicated D+/D− contacts and separate 5.1 kΩ CC resistors are connected.
VBUS groups join each other but remain isolated from main 5 V. No VBUS-sense
circuit is present; review the CM5 reference before deciding whether one is
required. Earlier completion notes are superseded. See the consolidated
[main design status](../documentation.md).

USBC2 and CN2 are placed. The layout note reports the 90-ohm USB profile
calculated for L1 over L2 ground, but the saved PCB has no USB differential
pair object/class membership and still uses the generic 15 mil/10 mil
differential rule. Ground-pad correction, ESD selection, VBUS treatment, pair
definition, profile-linked rule, and routing all remain open.

## Confirmed architecture

- The programming connector is separate from the main USB-PD power connector.
- Programming connector: a second HRO `TYPE-C-31-M-12`, LCSC `C165948`.
- Reusing the receptacle does not reuse the power-port circuit: this connector
  uses USB-device CC termination and USB 2.0 data, not another CH224A PD sink.
  ESD implementation and reference-based VBUS treatment remain open.
- Reuse of `C165948` is confirmed for Rev A to reduce unique BOM items.
- It carries the CM5 USB 2.0 D+ and D− device signals to a host computer.
- It is used with `nRPIBOOT` and Raspberry Pi `rpiboot` to expose the CM5 eMMC.
- It is not intended to power the complete carrier board.
- Programming-port VBUS must not be tied directly to `5V_MAIN`; that would
  create competing power sources between the host and main converter.
- Connector ground connects to the board ground plane.
- Low-capacitance USB ESD protection is required near the connector.
- Route D+ and D- as one 90-ohm differential pair, as required by the current
  official CM5 datasheet. Preserve polarity; USB 2.0 P/N swapping is not
  permitted.
- The USB-C programming receptacle requires the correct device/sink-side CC
  arrangement from an authoritative USB-C reference circuit.

## PCB-layout requirements

- Define `USB_P`/`USB_N` as a differential pair and derive its 90-ohm width
  and gap from the final JLCPCB stackup.
- The saved PCB's generic 15 mil/10 mil differential rule is a placeholder,
  not an approved USB geometry.
- Keep the pair over a continuous reference plane, minimize discontinuities,
  and avoid uncontrolled test-point stubs.
- Place the required low-capacitance ESD array close to `USBC2` and keep the
  protected path in line with the differential pair.
- Do not add a 90-ohm shunt resistor across D+/D-; controlled impedance is a
  transmission-line geometry requirement and the USB PHY handles termination.

## Planned schematic content

- Dedicated `C165948` USB-C receptacle.
- USB 2.0 D+ and D− path to the CM5.
- Correct USB-C device-side CC resistors.
- Low-capacitance ESD protection.
- Reference-based VBUS treatment; add sensing only if required by the reviewed design.
- Shield and ground treatment.
- Accessible D+/D− test access only if it can be provided without harmful stubs.
- Ground test access; VBUS-sense test access only if sensing is implemented.

## Flashing relationship

The programming connector supplies the USB data/recovery path. The main power
connector supplies adequate board power. Holding `nRPIBOOT` low during power-up
places the CM5 into USB recovery mode so `rpiboot` can expose the eMMC to the
development computer.

## Definition of done

- USB data routing reaches the correct CM5 pins with correct polarity.
- CC, ESD, VBUS treatment, shield, and ground are drawn from reviewed references.
- No direct host-VBUS-to-`5V_MAIN` path exists.
- The connector can be used while the board receives normal main power.
- The schematic supports both initial flashing and recovery of a corrupted
  eMMC image.

## References

- `Documentation/Research MD/programming.md`.
- `Documentation/Research MD/CM5-Connector-Wiring-and-Bringup.md`.
- Current CM5 datasheet and official CM5 IO reference design.

## Session notes

- 2026-09-18: Initial programming-USB draft created. This subsystem is a
  mandatory part of Schematic V1, not an optional accessory.
- 2026-09-19: Completed the programming-port schematic and imported its
  components into the PCB document. Placement and USB routing are next.
- 2026-09-28: Locked the programming USB 2.0 pair to 90 ohms differential
  from the current CM5 datasheet and recorded that polarity must not be
  swapped. Pair creation, ESD selection, stackup geometry, routing, and tuning
  remain open; no CAD change was made.
- 2026-09-28: Layout setup placed USBC2/CN2 and reportedly calculated the
  90-ohm profile. Saved-CAD review still found no USB pair object or
  profile-linked rule, so the interface is not routing-ready.

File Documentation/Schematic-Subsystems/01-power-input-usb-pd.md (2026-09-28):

# 01 — USB-C Power Input and Power Delivery

Last updated: 2026-09-19

## Open review actions — 2026-09-19

- Open: validate simultaneous CM5/Hailo/camera load against the 9 V/3 A
  source (27 W before conversion losses), fuse derating and transient demand.
- Proposed only: R1 `C2770993` → Basic `C23212`, same 6.8 kΩ/0603,
  100 mW/75 V/100 ppm/°C, with tolerance improved to 1%. The replacement
  does not retain the existing AEC-Q200 qualification. Confirm that is
  acceptable, and recheck stock and fee classification before substitution.

These actions are not implemented. Current release blockers are consolidated
in the [main design status](../documentation.md).

## Subsystem purpose

Accept DC power from an external USB-C PD charger, request 9 V, protect the
board input, and deliver the negotiated supply to the main 5 V converter.

## Current status

**Schematic complete and transferred to PCB.** The connector, negotiation
controller, requested voltage, and simplified fuse-plus-TVS Rev A protection
are implemented. The MP2329 enable network prevents startup from the default
5 V USB supply.

## Confirmed design

- This is the board's main power connector; it is separate from the CM5
  programming/recovery connector.
- Connector: HRO `TYPE-C-31-M-12`, LCSC `C165948`.
- The connector is a 12-pin mid-mount USB-C receptacle rated for 5 A/20 V and
  has through-hole mounting legs.
- USB-PD sink controller: `CH224A`, LCSC `C42459160`.
- The CH224A uses resistor configuration and requires no microcontroller.
- Requested input voltage: 9 V using the documented 6.8 kΩ configuration.
- CH224A `VBUS` must connect to `VHV` as required by its reference design.
- Retain the existing 1 µF/50 V/0603 capacitor `C15849`; no capacitor
  substitution is approved or required for the current design.
- The earlier TPS25947 eFuse decision is superseded; it is not part of Rev A.
- `USBC_Protection.SchDoc` contains the physical fast-acting fuse: Walter
  `1206T3A63V`, LCSC/JLCPCB `C354897`, rated 3 A/63 V.
- `Power Rails.SchDoc` contains the `SMBJ12A` TVS, LCSC/JLCPCB `C151251`.
- Rev A therefore retains fuse + TVS but omits the earlier TPS25947 eFuse.
- The MP2329 external enable divider uses 453 kΩ (`C25818`) from input to EN
  and 100 kΩ (`C25803`) from EN to ground. Including the MP2329's internal
  1 MΩ EN resistance, the nominal start threshold is approximately 7.5 V.
  Default 5 V USB input therefore remains below the intended start threshold,
  while a negotiated 9 V input enables the converter.
- A plain 5 V-only charger is not intended to operate the complete board.

## Planned schematic content

- USB-C receptacle and shield/ground connections.
- CH224A and all datasheet-required support connections.
- The confirmed 9 V configuration resistor.
- Fuse `C354897` in the input-current path and TVS `C151251` at the protected
  input node.
- Input and negotiated-voltage test points.
- A visible indication of successful negotiation where practical.
- A controlled path from negotiated VBUS to the MP2329 input.

## Dependencies

- The peak-power calculation in [02-main-5v-power.md](02-main-5v-power.md).
- The final definition of failed or incomplete PD negotiation behavior.
- Connector assembly capability and footprint verification.

## Definition of done

- The power connector, CH224A, and all required support parts are drawn.
- The 9 V request configuration is checked against the current datasheet.
- The fuse-plus-TVS Rev A protection topology is explicitly documented and drawn.
- The circuit cannot accidentally create a second power path through the
  programming USB connector.
- Connector shell and mounting contacts are correctly represented.
- Relevant voltage, status, and ground test access is provided.

## References

- `Documentation/documentation.md`, power-input decisions.
- `Documentation/Research MD/power-design-explainer.md`.
- CH224A and `TYPE-C-31-M-12` datasheets in `Documentation/Datasheets/`.

## Session notes

- 2026-09-18: Initial subsystem draft created from confirmed project records.

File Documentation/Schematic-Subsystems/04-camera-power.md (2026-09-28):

# 04 — Camera Power

Last updated: 2026-09-28

## Purpose

Provide a quiet, dedicated 3.3 V rail to the Raspberry Pi camera connector.

## Current status

**Critical correction required.** The AP2112 is now `U3` (formerly `U7`).
The 2026-09-24 PCB ECO retained the incorrect physical pin mapping, and the
camera output capacitor remains unverified. Earlier completion notes below
are not evidence of an implemented fix.

| U3 physical pin | Required function/connection | Saved PCB/ECO connection |
|---|---|---|
| 1 | VIN / main 5 V | Main 5 V |
| 2 | GND | Main 5 V — incorrect |
| 3 | EN / main 5 V | GND — incorrect |
| 4 | NC / unconnected | CN4-22 — incorrect |
| 5 | VOUT / camera 3.3 V, CN4-22 | No net — incorrect |

Correct the symbol designators/functions and placed instance, verify footprint
numbering against the [AP2112 datasheet](https://www.diodes.com/assets/Datasheets/AP2112.pdf),
then regenerate the ECO. C15 is input decoupling only; add the intended 1 µF
output capacitor from corrected VOUT to GND and check effective capacitance.
See the consolidated [main design status](../documentation.md).

## Confirmed design intent (not verified as-built)

- Regulator: Diodes Incorporated `AP2112K-3.3TRG1`, LCSC `C51118`.
- Input: `5V_MAIN`.
- Output: `3V3_CAMERA`.
- The output is fixed at 3.3 V with a maximum electrical rating of 600 mA.
- Input capacitor: 1 µF, 50 V, X5R, 0603, LCSC `C15849`, directly from
  `5V_MAIN`/VIN to GND.
- Output capacitor: 1 µF, 50 V, X5R, 0603, LCSC `C15849`, directly from
  `3V3_CAMERA`/VOUT to GND.
- `VIN` and `EN` connect to the same `5V_MAIN` net for always-on operation.
  The EN input must not float because the AP2112 contains an internal 3 MΩ
  pull-down.
- `NC` is intentionally left unconnected.
- The standard Raspberry Pi 22-pin camera connector receives 3.3 V on pin 22.
- A separate 1.8 V carrier-board camera rail is not required for Camera
  Module 3; the module generates its lower internal rails.
- The selected camera is the standard Raspberry Pi Camera Module 3 using the
  IMX708 sensor, not Camera Module 3 Wide. Its documented maximum load still
  needs to be confirmed. Treat 300 mA as a thermal review case, not a verified
  maximum.
- At 300 mA from a 5 V input, the LDO dissipates approximately 0.51 W. Using
  the datasheet's 184°C/W SOT25 junction-to-ambient figure gives an estimated
  94°C junction rise, so useful copper area and prototype thermal testing are
  required. Typical camera consumption is expected to be below this maximum.
- The camera rail is separate from the Hailo switching rail.

## Schematic implementation

- Open: correct physical pins 2–5 and add output decoupling as listed above.
- Open: verify the corrected VOUT reaches CN4-22 and has no connection to NC.
- Open: confirm rail/ground test access and use clear rail net labels.
- Open: close thermal margin for the actual camera. The 300 mA case gives
  about 134°C junction at 40°C ambient using the cited thermal resistance;
  a 600 mA electrical rating does not establish usable thermal capacity.

## Load-switch decision

- **Omitted from Rev A:** `TPS22918`, LCSC `C131941`.
- TPS22918 is a load switch, not a voltage regulator. It would only add
  separate rail isolation or power cycling.
- `AP2112K-3.3TRG1` (`C51118`) remains the confirmed 5 V-to-3.3 V camera LDO.

## Definition of done

- The complete LDO circuit is drawn from the current datasheet.
- Camera power and ground pins are fully connected.
- Capacitor values, voltage ratings, and placement intent are recorded.
- Thermal margin is checked for the planned camera load.
- Camera power enable behavior is coordinated with the CM5 camera controls.

## References

- `Documentation/documentation.md`, current camera-power decision.
- `Documentation/Research MD/power-design-explainer.md`.
- AP2112K and selected camera documentation.

## Session notes

- 2026-09-18: Initial subsystem draft created from confirmed project records.
- 2026-09-18: Recorded the intended LDO circuit using `C51118`, two `C15849`
  1 µF X5R capacitors, EN tied to `5V_MAIN`, and NC open. The later saved-CAD
  review superseded the completion claim: U3 is wired incorrectly and the
  output capacitor is missing. The 300 mA value remains a thermal review case.

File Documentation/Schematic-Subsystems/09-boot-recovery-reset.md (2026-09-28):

# 09 — Boot, Recovery, and Reset

Last updated: 2026-09-28

## Purpose

Allow the CM5 to boot normally from eMMC, enter USB recovery mode on demand,
and be reset or power-controlled during development and fault recovery.

## Current status

**Switch placed and ECO-connected; recovery operation unverified.** The
selected XUNPU `TS-1088R-02026`, JLCPCB/LCSC `C455280`, is now `SW` on the
schematic and PCB. The 2026-09-23 PCB ECO records `CN1-93` (`nRPIBOOT`) and
`SW-1` on `NetCN1_93`, with `SW-2` on GND. This supersedes the
2026-09-19 finding that no switch existed. Verify the current pad nets in
Altium, footprint/datasheet,
accessible placement, a labeled test point, and normal/recovery behavior.
The internal pull-up supports normal boot when the switch is released.
A separate CM5 power button remains intentionally omitted from Rev A.

## Confirmed boot model

- The selected CM5 variant contains eMMC; no microSD connector is required.
- Normal boot sequence is CM5 boot ROM → EEPROM bootloader → eMMC boot files →
  Linux → `systemd` → Watchdog services.
- Hailo and camera initialization occurs after Linux begins booting; neither
  device replaces the CM5 boot process.
- CM5 pin 93 is `nRPIBOOT`.
- Holding `nRPIBOOT` low during power-up enables USB boot/recovery.
- Releasing `nRPIBOOT` and power-cycling returns the CM5 to normal eMMC boot.
- Recovery control will be a normally-open momentary pushbutton from
  `nRPIBOOT` to ground. The CM5 provides the signal's internal pull-up.
- The recovery control must remain physically accessible with the CM5 installed.
- Selected switch: XUNPU `TS-1088R-02026`, JLCPCB/LCSC `C455280`;
  normally-open momentary SPST, two-terminal SMT, 3.9 x 2.93 mm body,
  2 mm height, 2.6 N operating force, 50 mA / 12 V rating, 100,000 cycles.
  JLCPCB lists it as Extended. This replaces TE `3-1437565-0` / `C86463`.
  See [JLCPCB listing](https://jlcpcb.com/partdetail/Xunpu-TS_1088R02026/C455280).
- Remaining work: verify the exact datasheet, symbol-to-pad mapping,
  footprint, and current PCB pad nets; add the labeled test point; place
  accessibly and route; verify released/pressed states and normal/USB boot.
  Placement and ECO connection are not functional validation.

## CM5 power-control decision

- CM5 pin 92 `PWR_BUT` replicates the Raspberry Pi 5 power button. A brief
  pull to ground requests wake or shutdown; holding it low for more than five
  seconds forces shutdown.
- CM5 pin 99 `PMIC_ENABLE` places the CM5 into its lowest power-down state when
  pulled low. Raspberry Pi recommends doing this only after OS shutdown.
- **Rev A decision:** do not fit a `PWR_BUT` pushbutton. Normal operation uses
  applied main power and software shutdown rather than a local power button.
- `PMIC_ENABLE` is not a reset button and will not receive a user pushbutton.

## Confirmed recovery workflow

1. Hold `nRPIBOOT` low.
2. Apply adequate power through the main power input.
3. Connect the programming USB-C connector to the development computer.
4. Run Raspberry Pi `rpiboot`/the supported mass-storage utility.
5. Write the operating-system image to the exposed eMMC.
6. Stop the flashing process and release `nRPIBOOT`.
7. Power-cycle and boot from eMMC.

## Planned schematic content

- Accessible pushbutton control for `nRPIBOOT`, plus a labeled test point.
- Defined normal and recovery states following the official CM5 reference.
- Clearly named recovery, reset/control, and ground test points.
- Status indication where it does not load a boot-critical signal.

## First software-image plan

- Raspberry Pi OS 64-bit.
- Correct CM5 bootloader and Device Tree configuration.
- Camera and PCIe interfaces enabled.
- Hailo runtime/driver support.
- Wi-Fi and SSH configuration.
- Serial console enabled for the debug UART.
- A diagnostic boot stage before the complete Watchdog application.

## Definition of done

- Normal eMMC boot and forced USB recovery are both supported by hardware.
- Recovery controls are accessible and clearly labeled.
- Programming USB and UART remain usable when Linux or Wi-Fi is unavailable.
- A bring-up operator can determine which control state produces normal boot
  versus recovery boot without modifying the board.

## References

- `Documentation/Research MD/programming.md`.
- Current Raspberry Pi Compute Module flashing documentation.
- Current CM5 datasheet and official CM5 IO reference design.

## Session notes

- 2026-09-18: Initial boot/recovery draft created with additional explanation
  because this is a high-priority learning and bring-up area.
- 2026-09-19: Earlier completion claim was superseded by the saved-CAD review;
  recovery control was absent.
- 2026-09-20: Selected C455280 in place of C86463. Bill explicitly confirmed
  the button remains unfinished; implementation and verification are open.
- 2026-09-28: Current CAD contains `SW`; the 2026-09-23 ECO connected it
  between `CN1-93` and GND. Access and functional recovery remain open.

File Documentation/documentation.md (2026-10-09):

# Documentation — Wireless Watchdog: CM5 Carrier Board

Last updated: 2026-10-09

This is the daily working document for current status, active blockers, and
session changes. [`Journal.md`](Journal.md) is the source of truth for verified
project decisions; update this working summary whenever a verified journal
decision changes the active design.

## Immediate PCB finishing work - 2026-10-09

Routing is substantially implemented in the saved PCB: all nine differential
pairs are defined and each member has top-layer tracks. Finish corner GND
vias, revise the board outline, and add/re-pour the required polygon copper.
Then refresh connectivity and resolve remaining DRC items in Altium. Final
routing, impedance, and release sign-off remain open.

The read-only saved-file audit found 85 connection records (83 GND and two
`NetCN1_78`), a broadly scoped 90-ohm differential rule, and unequal USB
track-only lengths. No DRC report was found, so a small remaining violation
count is not independently confirmed. See the [PCB audit](PCB-Audit-2026-10-09.md) for evidence
and the limits of this inspection.

1. Add corner GND vias and review stitching against the revised outline.
2. Revise the board shape; check component, copper, and connector clearances.
3. Add/re-pour polygon copper; inspect islands and return paths.
4. Refresh connectivity, resolve `NetCN1_78`, and check the remaining GND
   connections after the pours. Saved connection records are not a fresh DRC.
5. Correct or verify differential-rule scopes and profile assignments,
   including the 100-ohm MIPI requirement; review USB pair length/skew.
6. Run final DRC after the outline/via/pour changes, then complete mechanical,
   silkscreen, ERC/ECO, BOM/CPL, and manufacturing-output reviews.

## Historical blockers requiring final re-verification — 2026-09-29

> **Historical review checkpoint:** Retain these findings until each affected
> item has been re-verified. Start with the 2026-10-09 finishing list above, then use
> [`Schematic-Subsystems/README.md`](Schematic-Subsystems/README.md) for the
> working order and affected subsystem files for implementation details. This
> section is expected to change as items are resolved or new blockers appear.

PCB transfer and a clean compile/ECO were reported on 2026-09-19, but the
subsequent saved-CAD review reopened schematic completion. Both CM5 connectors
retain unique physical pin designators `1–100`; the selected JST GH UART is
present. The 2026-09-28 reconciliation found **43 schematic and 43 PCB
components**, with all placements represented in the saved LiveBOM's 29
catalog entries (28 distinct LCSC codes). The earlier 42-component count is a
historical snapshot. These
**open corrections and checks** remain before release:

The CM5 connector component is **not an open correction**. On 2026-09-29,
`CN1` and `CN2` were confirmed as Amphenol `10164227-1001A1RLF` / LCSC
`C6782225`; both 100-pin schematic symbols and the shared 100-pad, 0.40 mm
footprint match the manufacturer land pattern. No connector change is needed,
and both placed instances are approved for routing. Final module alignment,
clearance, and 1:1 fit remain board-level placement checks.

1. Correct the AP2112 camera LDO, now `U3` (formerly `U7`): physical pins are
   1 VIN, 2 GND, 3 EN, 4 NC, 5 VOUT. The 2026-09-24 ECO still has pad 2 on
   the input rail, pad 3 on GND, pad 4 on camera power, and pad 5 unconnected.
   Add and verify the missing output capacitor.
2. Recheck and correct the C8/C9 Hailo output connections identified in the
   2026-09-19 saved-CAD review. The Hailo buck is now `U1` (formerly `U3`).
3. Recheck programming USB signal-ground contacts under the current USB-C
   designators, `USBC 1` and `USBC2`; add or resolve USB data ESD protection.
   The prior review used `USBC1` and must not be treated as a current
   designator map.
4. Verify the placed recovery switch `SW`: the 2026-09-23 PCB ECO connects
   `CN1-93` to `SW-1` and GND to `SW-2`. Accessible placement, a labeled test
   point, and functional USB recovery remain unverified.
5. Resolve CN3's `91302-42-067RDM` part versus `91302-32-067RDM` footprint
   and 3D-model identity against the manufacturer drawings before fabrication.
6. Resolve the LiveBOM's unknown part-choice statuses, then export and review
   a quantity-bearing purchasing BoM. Its `Name`, `Source`, `Value`,
   `Comment`, and `Footprint` fields now match the placed schematic parts.
7. Verify U5's MP2329 land pattern against its manufacturer drawing. Its
   current QFN-11 footprint is named for MP2384; matching package class and
   pin functions do not by themselves certify the copper land dimensions.
8. Define and verify USB-PD startup and failure behavior: initial 5 V attach,
   successful or failed 9 V negotiation, cable removal, and negotiation
   restart. Confirm how CH224A status or another UVLO/gating method prevents a
   marginal 5 V brownout state.
9. The selected camera is the standard Raspberry Pi Camera Module 3 using the
   IMX708 sensor, not Camera Module 3 Wide. Verify its two-lane cable path,
   FPC contact orientation, current requirement, module clearance, and
   camera-control mapping. Close the camera load and AP2112 thermal assessment.
10. Complete the simultaneous CM5/Hailo/camera peak-power budget, converter
    losses, startup transients, fuse derating, charger capability, and cable
    capability.
11. The PCB now has an approximately 100 mm x 60 mm working outline and all 43
    components are inside it, but the mechanical envelope is not frozen.
    Verify mounting holes, CM5 and M.2 retention, connector edges,
    camera-cable access, antenna keepout, heatsink access, cooling, and a 1:1
    fit check before release.
12. The four-layer stack and basic clearance/width/via rules are configured,
    and stackup-based impedance profiles were reported as calculated. Complete
    and verify the locked high-speed PCB rules: three PCIe pairs at
    90 ohms differential, five MIPI CSI-2 pairs at 100 ohms differential, and
    the programming USB 2.0 pair at 90 ohms differential. Define all nine pair
    objects, populate their classes, connect the routing rules to the impedance
    profiles, and confirm the calculated geometry with JLCPCB. Also define
    skew, reference-plane, power-current, clearance, and edge constraints.
    Release requires reviewed ERC/ECO/DRC, return-path and plane review,
    connector pad maps, mechanical fit, BoM/CPL, fabrication and drill outputs.
13. Confirm assembly support for the fine-pitch and mechanically supported
    connectors, then recheck stock and approved alternates when the BoM is
    stable.

Verify every corrected physical pad net after a fresh ECO. The documentation
reviews did not run Altium ERC or DRC.

**Proposed only:** replace C4 `C466768` with Basic `C14663`, and R1 `C2770993`
with Basic `C23212`. R1's automotive qualification is not retained; confirm it
is unnecessary and recheck stock/assembly classification before selection.
No BOM substitution has been implemented. The current unresolved validation
tasks are listed above, and the
[subsystem dashboard](Schematic-Subsystems/README.md) gives the working order.

## Current design summary

The electrical findings below come from earlier reviews and are retained for
re-verification; this routing audit does not establish that they are still
present or that they have been corrected. The October 9 audit supersedes the
older no-routing/no-pair-object status.

The TPS54302 `3V3_HAILO` buck, AP2112 `3V3_CAMERA` LDO, Hailo M.2-to-CM5 PCIe
interface, and 22-pin CSI-to-CM5 interface are drawn. The camera subsystem is
not complete because U3 is wired incorrectly, its output capacitor is missing,
and cable orientation and layout checks remain open. The M.2 link
uses PCIe lane 0, reference clock, `PERST#`, and `CLKREQ#`; lane 1,
`PEWAKE#`, CM5 `PCIE_nWAKE`, and CM5 `PCIE_PWR_EN` are intentionally unused
in Rev A. The CSI interface wires all four MIPI0 data lanes, MIPI0 clock,
`SCL0`/`SDA0`, `CAM_GPIO0`/`CAM_GPIO1`, `3V3_CAMERA`, and grounds. The
authoritative MIPI0 CM5 pins are 115/117, 121/123, 127/129, 133/135, and
139/141; pin 141 is lane 3 positive, not lane 0 negative.

The high-speed routing targets were verified against the current official CM5
datasheet on 2026-09-28. The three used PCIe pairs (TX, RX, and reference
clock) require 90 ohms differential routing; the four MIPI data pairs and MIPI
clock require 100 ohms differential routing; and programming USB D+/D- requires
90 ohms differential routing. This supersedes the older 85-ohm PCIe note. The
Hailo module datasheet provides no conflicting target and defers to the PCIe
M.2 specification. CM5 includes coupling capacitors on its PCIe transmitter,
and the M.2 module supplies its transmitter-side coupling; do not duplicate
them. Controlled impedance is set by stackup and trace geometry, not by adding
parallel termination resistors. The September/October 5 snapshots lacked differential-pair objects. The
October 9 audit confirms nine saved pairs and routed tracks; final rule scope,
impedance, and skew verification remain open (see the PCB audit).

## Historical PCB layout setup status — 2026-09-28

The board has a working outline of approximately 100 mm x 60 mm and a
four-layer stack: L1 `SIG 1`, L2 internal `GND`, L3 internal `PWR`, and L4
`SIG 2`. All 43 components are placed on the top side and inside the outline,
but placement does not close the open schematic corrections, footprint and
mechanical checks, or final clearance review. Routing has not begun.

The configured general rules are 0.15 mm clearance, 0.20 mm minimum and
0.25 mm preferred trace width, and 0.60 mm/0.30 mm through vias. The external
layout note reports a 1.0 mm maximum general width, while the current saved
PCB rule serializes a 0.50 mm maximum; reconcile this in Altium. Power nets
will require explicit current-based width/plane rules rather than relying on
the general signal-width rule.

The intended plane strategy is a continuous L2 ground plane and a continuous
L3 main-5-V plane. High-speed CSI, PCIe, and USB pairs should remain on L1 over
uninterrupted L2 ground where practical; avoid L4 for them because its adjacent
reference is the L3 power plane. The layout note reports that the main 5 V PCB
net was renamed to `5V` and assigned to L3, but the current saved PCB net table
still contains `NetC2_1` and the project documentation/schematic use
`5V_MAIN`/`5V_6.5A`. Re-open the PCB, verify and save both plane assignments,
then make the schematic and PCB rail name authoritative and ECO-stable.

Stackup-based 90-ohm and 100-ohm profiles were reported as calculated, but
the saved PCB still contains no differential-pair objects and retains the
generic 15 mil/10 mil differential routing rule. The reported CSI pair class
is not populated, and the routing rules are not connected to the profiles.
Finish and save the nine pair definitions/classes/rules before routing, then
verify the calculated widths/gaps against JLCPCB capability.

Route the MP2329, TPS54302, AP2112, their decoupling, and other critical power
loops first. Then route CSI/PCIe/USB and sensitive controls, ordinary signals,
power connections, ground stitching, and silkscreen. Mechanical-layer graphics
are reference/documentation geometry, not copper or silkscreen; Top Overlay is
actual silkscreen and must be checked against pads and component bodies. A
previous stale/corrupt footprint-instance DRC symptom appeared to clear after
replacing affected placed instances; final DRC must confirm it has not returned.

The first revision uses a simpler power-input design: the TPS25947 eFuse has
been removed because its added complexity is not appropriate for this first
board. The earlier eFuse selection and topology discussion remain in the
project history, but the eFuse is not part of the current schematic.

The first 100-pin CM5 connector now has its GPIO reference decision: pin 78
(`GPIO_VREF`) ties to the CM5's 3.3 V output pins 84 and 86, selecting 3.3 V
GPIO signaling. The Hailo-8L M.2 custom-symbol pinout is now also locked from
the Hailo module datasheet: all five 3.3 V contacts and nine grounds are used,
PCIe lane 0 connects to the CM5 with endpoint TX/RX crossed correctly, lane 1
is explicitly no-connect, and the reference-clock/reset/clock-request signals
are assigned. See `Research MD/PCIe-x1-Differential-Pairs-Explainer.md` for
the pin-by-pin table.

Rev A leaves `LED_nACT` (pin 21), `VBAT` (76), `PWR_BUT` (92), `LED_nPWR`
(95), and `PMIC_ENABLE` (99) unused; they receive no-connect markers.
`nRPIBOOT` (93) remains required for recovery. Optional status work may add
resistor-limited LEDs across `5V_MAIN`, `CM5_3.3V`, `3V3_HAILO`, and
`3V3_CAMERA`. Rail LEDs indicate voltage presence only; they do not prove
load capacity or every connector-pin connection.

The two local 3.3 V power branches are now selected. `5V_MAIN` from the
MP2329 feeds a dedicated **TPS54302DDCR** 3 A switching regulator (JLCPCB/LCSC
**C311983**) for `3V3_HAILO`; 5 V must not be applied directly to the Hailo
module. A separate `5V_MAIN` branch feeds an **AP2112K-3.3TRG1** 600 mA LDO
(JLCPCB/LCSC **C51118**) for `3V3_CAMERA`. The standard Raspberry Pi 22-pin
CSI connector requires only 3.3 V on pin 22; the camera module makes its lower
internal rails locally. The branches remain separate so Hailo load transients
and switching noise do not directly share the camera's 3.3 V rail.

The bring-up architecture is now defined. One USB-C connector is dedicated to
board power. A second USB-C connector is dedicated to CM5 programming and
recovery. The CM5's onboard eMMC is flashed through USB mass-storage mode; no
external SD-card socket is needed for the full CM5 variant. CM5 pin 93
(`nRPIBOOT`) is ECO-connected through an XUNPU `TS-1088R-02026`
(JLCPCB/LCSC **C455280**) normally-open momentary pushbutton to GND. A
labeled test point is still planned for USB recovery during power-up. The
switch was selected 2026-09-20,
replacing TE `3-1437565-0` / `C86463` for simpler two-terminal wiring.
**The switch is now placed and transferred:** the 2026-09-23 PCB ECO connects
`CN1-93` to `SW-1` and `SW-2` to GND. Footprint/datasheet validation,
accessible placement, a labeled test point, routing, and functional checks
remain open. The switch has a 3.9 x 2.93 mm body, 2 mm height, 2.6 N operating
force, 50 mA / 12 V rating, and Extended classification. Verify the exact
datasheet and land pattern before release. The CM5 provides the
10 kΩ pull-up to 3.3 V; no additional pull-up is planned.
The three-pin UART debug connector uses pin 55
(`GPIO14` / `UART0_TX`) and pin 51 (`GPIO15` / `UART0_RX`), plus ground, for
early-boot diagnostics. Wi-Fi and SSH are used for normal development after
Linux boots.

The carrier board does not require a separate microcontroller or bridge chip
for these functions. It routes the CM5 signals directly to the power circuit,
USB programming connector, UART header, camera, and Hailo PCIe interface.
See `Research MD/CM5-Connector-Wiring-and-Bringup.md` for the complete
signal-level map and staged bring-up plan.

Ethernet remains excluded from this revision. The CM5 already includes an
Ethernet PHY, but the project currently has no wired-network or PoE
requirement; adding the MagJack, protection, and four high-speed pairs would
increase board area and routing complexity without being necessary for the
Watchdog device.

## Daily changes and session log

A running summary, newest entry at the bottom. This lets you pick up where
the last work session left off without reading the whole file.

- **Session 1 (2026-07-22):** Picked the main parts — CM5 (4GB RAM, 32GB
  storage, WiFi built in), Hailo-8L AI chip on an M.2 slot (connects at PCIe
  Gen2 x1 speed, same setup Raspberry Pi's own AI Kit uses), a camera
  connector with its own control wires, a two-stage power system (main power
  chip → local regulators near each part), and a debug port (CM5 only,
  3 pins, 3.3V signal level). Confirmed CM5 over CM4 and a custom board over
  Raspberry Pi's AI HAT+ (reasons below under "Decisions locked"). Looked
  into pricing for the Hailo-8L (Raspberry Pi's AI Kit version is
  discontinued, third-party versions run $120-180, avoid international
  shipping forwarders). Next step: build the power budget spreadsheet
  (still not done), then order the CM5, Hailo-8L, and camera.
- **Session 2 (2026-07-25):** Redrew the "Main Compute Module" diagram
  (`Graphical/Carrier Board PCB.canvas`) as a left-to-right tree (board →
  root → CM5/Hailo-8L/Camera → their connector/power/signal-quality details),
  and turned each detail line into a checkbox. Then researched and picked
  connectors for all three parts (see "Hardware updates & discoveries"
  below). Also researched the power-input chain (power negotiation chip,
  protection chip, voltage converter, surge protector), the debug/control
  wiring, and the local regulators — and found that the Hailo-8L actually
  draws much more power than first assumed (6.6W / 2A, not "a few hundred
  mA"). Found three open questions: does the protection chip have enough
  voltage headroom, what part handles the Hailo-8L's power converter, and
  which exact camera model to buy. Next step: close those three questions,
  finish the power budget, then order parts.
- **Session 3 (2026-07-30):** Finished the power budget spreadsheet
  (closing a task from Session 1) — the real total power draw is **about
  13W with safety margin**, much lower than the ~20-23W first guessed. That
  old number came from a review of the CM5 running overclocked with a
  cooling fan, which doesn't apply here. Switched the power-negotiation chip
  (CH224K → CH224A, better voltage safety margin) and the main voltage
  converter (TPS54560 → MP2329GG-Z), and now request 9V from the charger
  instead of 20V since the corrected power number doesn't need it. Also
  double-checked the Hailo-8L's power needs directly in its datasheet
  (`Datasheets/4746521.pdf`, section 3.1): confirmed max draw is 6.6W/2A at
  full load, with typical use around 1.4-1.9W. This confirms a simple linear
  regulator (LDO) is not a good fit for that rail — it needs a real
  switching converter rated for at least 2A. Also cleaned up the project
  notes: deleted two files (`documentation.md`, `status.md`) that just
  repeated what's already in this file, and switched from separate
  per-session log files to one running `Journal.md`. Next step: pick the
  ≥2A converter for the Hailo-8L's power rail (oldest open item), pick the
  protection-chip part, and confirm the MP2329's resistor values against
  what's actually in stock.
- **Session 4 (2026-08-01):** Two planning decisions this session, no new
  parts picked. (1) **Timeline pushed back about 2.5 weeks** to add a
  professor review before ordering the board (class starts Sep 2, review +
  fixes budgeted about 2 weeks after that) — see "Timeline" below for exact
  dates. The internal work deadlines (schematic done Aug 9, layout done
  Aug 23) stay the same; the extra time is added *after* layout is done, not
  mixed into the design work itself. (2) **Changed the assembly plan**: the
  whole board — including connectors and other through-hole parts — will
  now be machine-assembled by JLCPCB, with no hand-soldering step. This
  fixes an earlier plan that was never really realistic: the 100-pin,
  very-fine-pitch CM5 connector was never something to hand-solder safely.
  **Superseded 2026-09-29:** the verified Amphenol CM5 connector is SMT with
  no hold-down holes; only the M.2 and USB-C connectors require any separate
  through-hole assembly consideration. Confirm whether those parts need a
  separate line item on the
  assembly quote. The USB-C connector was added to the schematic this
  session, but the exact part number isn't picked yet. Next step (same as
  before): pick the protection chip, pick the USB-C connector part, pick the
  Hailo-8L power converter, confirm the MP2329's resistor values are in
  stock.
- **Session 5 (2026-08-08):** Closed out the input-protection stage.
  **Picked all three parts:** TVS **SMBJ12A** (LCSC C151251), eFuse
  **TPS25947** (LCSC C3662799), backup fuse **1206T3A63V** (LCSC C354897,
  confirmed 18.4k in stock). Also **corrected the protection-stage
  topology** — the original order (TVS → fuse → eFuse) had a gap: a shunt
  TVS placed *before* the fuse means a TVS that fails shorted (a known TVS
  failure mode under an over-energy event) shorts VBUS straight to ground
  without the fuse ever seeing it. Reordered to **fuse → TVS → eFuse** (see
  "Input protection" below) so the fuse backs up both a shorted TVS and a
  shorted eFuse, not just the eFuse. This is a first-principles fix, not
  copied from a reference design yet — **still needs to be checked against
  the Spectre RM DevBoard's power-input section** before it's treated as
  final, consistent with this project's rule of never inventing protection
  topology from scratch. Next step: pick the USB-C connector part, pick the
  Hailo-8L power converter, confirm the MP2329's resistor values are in
  stock, then run the two planned LTspice simulations.
- **Session 6 (2026-08-08):** Checked whether any power-chain part
  qualifies for JLCPCB's Basic parts library (no per-part setup fee),
  since budget was raised as a concern. **None do** — CH224A, MP2329,
  USBLC6-2SC6, SMBJ12A, TPS25947, 1206T3A63V, AP2112K-3.3, TPS22965, and
  TPS22918 are all Extended (checked against JLCPCB's live parts database,
  not guessed). The only Basic-library TVS at all is SMBJ6.5CA, whose
  6.5V standoff is too low for our 9V rail — not usable. This isn't
  unusual: USB-PD/eFuse/voltage-specific protection parts essentially
  never make the Basic list. At $3/unique extended part (one-time per
  order, not per-unit), the 9 parts above run about $27 total — a fixed
  cost, not worth redesigning around. A stock-drop concern raised during
  this check (TPS25947, TPS22965) turned out to be a false alarm from a
  stale third-party mirror (jlcsearch.tscircuit.com) — LCSC's own live
  page shows TPS25947 at 1,461 units and TPS22965 at 317, both healthy.
  Lesson: check LCSC/JLCPCB directly for stock, not third-party mirrors.
- **Session 7 (2026-08-09):** Picked the USB-C connector part, closing the
  oldest open item in the power-input section. **TYPE-C-31-M-12** (HRO
  Electronics, LCSC **C165948**) — a 12-pin mid-mount USB-C receptacle,
  rated 5A/20V. Checked against the design's actual needs: CC1/CC2 present
  (required for CH224A's PD negotiation and cable-orientation detection),
  VBUS/GND spread across multiple pins, DP1/DN1 + DP2/DN2 for the USB 2.0
  debug/flashing line (mirrored pair, no SuperSpeed pins needed since no
  USB 3.0 is planned). At the fixed 9V request and ~13W budget, actual
  draw (~1.5A) sits well under the 5A rating, and 20V covers the 9V request
  with margin. SBU1/SBU2 are broken out but unused (alt-mode/audio only) —
  left no-connect. **Confirmed this part has through-hole mounting legs**
  (2× Ø0.50 mounting holes), not pure SMT — same open question as the DF40
  connector and M.2 socket on whether JLCPCB's assembly quote needs a
  separate through-hole line item (see "Outstanding" below). It's also a
  board-edge-mount part (datasheet calls out "PCB EDGE" against one side of
  the footprint) — normal for any USB-C receptacle, just needs the board
  outline to line up with it. Datasheet saved to
  `Datasheets/C165948.pdf`. Next step: footprint (Bill starting this now),
  then the Hailo-8L local converter (now the oldest unpicked part in the
  power chain).

- **Session 8 (2026-08-10):** Started the main power schematic from the
  selected USB-C connector. Locked the working names and topology:
  USB-C VBUS pins -> `USB_VBUS` -> fuse `F1` -> `FUSED_VBUS`; from
  `FUSED_VBUS`, the CH224A, TVS, and TPS25947 input branch in parallel,
  followed by the TPS25947 output -> MP2329 -> `5V_MAIN`. The CH224A is a
  controller on the VBUS node, not a series converter. For the CH224A, use
  the A/Q reference circuit, connect pin 1 `VHV` and pin 8 `VBUS` to the
  same `FUSED_VBUS` net, and use 6.8k ohms from CFG1 to ground for the 9V
  request. CFG2/CFG3 may float when I2C is not used; pins 4/5 DP/DM are
  no-connect if BC1.2 is not used, while CC1/CC2 (pins 7/6) remain connected
  to the USB-C connector. Confirmed the C165948 mapping: all VBUS contacts
  together, all GND contacts together, A6/B6 as USB D+, A7/B7 as USB D-,
  SBU1/SBU2 no-connect, and EH1-EH4 shell contacts to ground. Removed the
  copied Altium directory from the GitHub documentation repository; the
  authoritative Altium project is outside it at
  `C:\Users\Bill\Desktop\Bill's Folder\Altium\Project Watchdog`.

- **Session 9 (2026-08-16):** Defined the CM5 programming and boot plan. The
  board is programmed by flashing the CM5's onboard eMMC, not by programming a
  separate carrier-board microcontroller. The normal boot chain is CM5 ROM →
  EEPROM bootloader → eMMC → Linux → systemd → Watchdog services. The PCB
  needs an accessible USB 2.0 programming path, `nRPIBOOT` recovery control,
  a 3.3V debug UART, reset/power control, and status indicators. Added
  `Research MD/programming.md` with the full bring-up and recovery plan.
  The current power-rail datasheets from the local Obsidian project folder
  were copied into `Documentation/Datasheets`, including the current
  `TPS259470ARPWR` datasheet. Tomorrow: read the programming note, finish
  connecting the CH224A PD request node to the fuse, TVS, eFuse, and MP2329
  using the current local datasheets, and review the resulting schematic.
- **Session 10 (2026-09-08):** Locked the Hailo-8L M.2 custom-symbol pinout
  from the Hailo Rev. 4.0 module datasheet and mapped PCIe lane 0, reference
  clock, reset, and clock request to the current CM5 pins. Lane 1 and all
  Hailo-unused contacts are explicit no-connects; configuration contacts are
  reserved for optional module detection. Recorded that `5V_MAIN` still
  needs two separate local power branches: a ≥2 A 3.3 V switching rail for
  the M.2 socket and a camera regulator feeding the CSI-2 connector after its
  voltage/pinout is verified. No Altium binary was changed and nothing was
  pushed. The component-selection and CSI-voltage portions of this checkpoint
  were superseded by Session 11; CAD wiring and sequencing remain open.
- **Session 11 (2026-09-08):** Closed the two local 3.3 V power-rail choices.
  The Hailo M.2 branch uses TI **TPS54302DDCR**, JLCPCB/LCSC **C311983**, a
  3 A synchronous adjustable buck configured for 3.3 V. The camera branch
  remains separate and uses Diodes Incorporated **AP2112K-3.3TRG1**,
  JLCPCB/LCSC **C51118**, a fixed 3.3 V/600 mA LDO. Confirmed the Raspberry Pi
  22-pin CSI connector takes 3.3 V on pin 22 and does not require a carrier
  1.8 V input. Stock checked during selection: C51118 had 64,064 units at
  JLCPCB and C311983 had healthy distributor stock. No commit or push was
  requested.
- **Session 12 (2026-09-09):** Normalized the M.2 and local-power information
  across the project documentation. The PCIe explainer is the detailed
  technical reference for the Hailo socket pin map; the power-design explainer
  is the detailed technical reference for the `5V_MAIN` → `3V3_HAILO` and `3V3_CAMERA`
  branches; this file and `Journal.md` retain the concise status/history.
  Updated the design audit to show the Hailo regulator selection as resolved
  while keeping CAD implementation, power verification, and reset sequencing
  open. Documentation changes are local only; nothing was pushed.
- **Session 13 (2026-09-18 to 2026-09-19):** Completed and sourced the
  TPS54302 Hailo buck passives and recorded the intended AP2112 camera LDO,
  whose completion claim was later superseded by the U3 saved-CAD findings. Consolidated
  the CM5 and M.2/CSI schematic sheets, and wired the M.2 PCIe and full 22-pin
  CSI interfaces to the CM5. Corrected misleading CM5 MIPI display labels and
  locked the authoritative pin map. Changes were committed and pushed through
  commit `4f6d2bf`; PCB differential routing and remaining base-interface/ERC
  work are the next phase.
- **Session 14 (2026-09-28):** Established the approximately 100 mm x 60 mm
  working outline, placed all 43 components, and configured the four-layer
  `SIG 1`/`GND`/`PWR`/`SIG 2` stack plus basic clearance, width, and via rules.
  The layout note reports continuous L2 ground and L3 5 V planes and completed
  impedance calculations, but differential-pair objects/class membership and
  profile-linked routing rules remain unfinished. Raw saved-PCB review also
  found the main rail still serialized as `NetC2_1`, no pair objects, the
  generic differential rule, and a 0.50 mm rather than reported 1.0 mm general
  maximum width. Verify/save those items in Altium. Routing starts with power
  converter and decoupling loops, then the nine high-speed pairs.

### 2026-10-09 - Saved PCB routing audit

Independently inspected the October 8 saved PCB. Nine differential pairs and
substantial copper routing are present. Updated the immediate work to corner
GND vias, outline revisions, polygon pours, connectivity cleanup, differential
rule/USB skew review, and final DRC. Evidence and inspection limits are recorded
in [the audit](PCB-Audit-2026-10-09.md). No CAD changes or DRC execution occurred.

## Project summary

Summer 2026 goal: design a custom **CM5 carrier board in Altium** (PCB
design software) that turns the Watchdog device into a **standalone smart
camera** — CM5 computer + Hailo-8L AI chip + camera, all on one custom
4-layer circuit board. The AI processing moves onto the device itself; the
old setup (PC server + video streaming pipeline) goes away. The alarm system
stays the same: detection → WiFi message → ESP32 gateway → radio signal →
alarm unit.

Why the deadline matters: **fall new-grad job recruiting.** The board needs
to be built, working, and documented as a finished portfolio piece in time
for that.

> **Timeline note (2026-08-01):** the target finish date has slipped from
> "late September" to a more realistic **mid-to-late October**, because of
> the Session 4 decision to add a professor review before ordering the
> board, plus normal manufacturing and part-sourcing time. This is a
> deliberate tradeoff (a correct board matters more than the calendar date),
> but it's worth double-checking that mid-October still works for the
> recruiting timeline. Full breakdown under "Timeline" below.

The design approach was checked twice against "is this just reinventing the
Raspberry Pi AI HAT+" and against a full rethink from scratch (see
"Decisions locked" and "Architecture reasoning" below) — both times the
answer was to keep building the custom board. The AI HAT+ only solves the
AI-chip connector problem and still needs a full separate Raspberry Pi 5
underneath it. Custom CM5 boards are also still rare (the CM5 only came out
in late 2024), unlike the older, well-documented CM4.

## Locked components

- **CM5**: 4GB RAM, 32GB built-in storage, WiFi. (A 2GB version was
  considered when 4GB prices spiked due to a shortage — the real price
  difference between 2GB and 4GB is only about $25; resellers were just
  marking up the sold-out 4GB version by over $100. The 4GB version avoids
  running out of memory during heavy tasks like compiling OpenCV from
  source code — the 2GB version would work for normal use but was riskier
  for development.)
- **Hailo-8L**, an AI chip rated at 13 TOPS (trillion operations per
  second — a measure of AI processing speed), on an M.2 B+M connector
  (2242 size), rated for PCIe Gen3 x2 (a faster connection standard than
  what we'll actually use).
  - Raspberry Pi no longer sells this chip by itself (their AI Kit is
    discontinued, and they've said they won't sell the Hailo-8L without
    their own HAT board). Buy it from third-party sellers (Waveshare,
    Yahboom on Amazon) instead, or use the Hailo-8 (a similar but
    higher-performance chip, 26 TOPS, similar price) if the 8L isn't
    available. Avoid international shipping-forwarder websites — one $99
    part quoted came out to $154 after forwarder shipping fees.
  - **The CM5 only exposes a PCIe Gen2 x1 connection** externally (its
    internal chip can technically go faster, but Raspberry Pi limits the
    external connector to Gen2 for signal-quality reasons). The Hailo-8L
    will automatically negotiate down to this slower connection — this is
    completely normal and is the exact same setup Raspberry Pi's own AI Kit
    uses (Pi 5 + Hailo-8L), which is proven to work. This only reduces data
    transfer speed, not the chip's actual AI processing power (13 TOPS
    stays the same). The data going back and forth (detection boxes and
    labels, not raw video) is small enough that the slower connection is
    still plenty fast.
  - The board uses a 67-contact M-key socket that accepts the Hailo-8L's
    B+M-key edge. The socket exposes both Hailo PCIe lane sets, but only one
    set (lane 0) is wired because the CM5 exposes only x1; lane 1 is left
    unconnected.
- **Camera**: connects over CSI-2 (a 4-wire-pair video interface, plus a
  clock wire, wire lengths need to be closely matched) to the CM5. Also
  needs a **separate 2-wire control connection (I2C)** for camera settings
  (exposure, gain, resolution) — easy to miss since it's separate from the
  video wires. The selected camera is the standard Raspberry Pi Camera Module
  3 using the IMX708 sensor, not the Wide variant. The official
  [CM5 datasheet](https://datasheets.raspberrypi.com/cm5/cm5-datasheet.pdf) specifies
  internal **1.8 kΩ pull-ups to `CM5_3.3V`** on `SCL0` and `SDA0`, so the
  carrier does not add another pull-up pair by default.

## Decisions locked

- **A custom carrier board, not a HAT (add-on board), not a full computer
  board.** The CM5 handles the hardest parts (the dense chip packaging,
  memory, WiFi certification); everything else is built around it.
- **CM5 over CM4** (re-confirmed). They use the same connector family but
  **different pin arrangements (~23 pins differ)** — so none of the
  connector wiring work carries over between them. The CM4 is also slower
  (CPU, RAM, storage) and has no USB 3.0, with the same PCIe speed limit as
  the CM5 anyway — so switching would give up performance for no real
  benefit. CM4 boards are also extremely common already (lots of tutorials
  and off-the-shelf kits), while CM5 boards are still rare, which works
  against the goal of building something that isn't already a solved
  problem.
- **Altium** (the PCB design software, available through an NYU license).
  Existing reference designs (in KiCad, a different tool) get imported just
  to study, not copied directly.
- **4 layers**, JLCPCB's controlled-impedance stackup (a specific
  layer/material setup that keeps signal quality consistent), **full
  JLCPCB machine assembly for every part — including connectors and other
  through-hole parts** (changed 2026-08-01; no hand-soldering planned at
  all). This replaces the earlier plan below, which wasn't realistic anyway
  for a connector with 100 tiny 0.4mm-spaced pins.
  **Still open:** confirm with JLCPCB whether the M.2 socket and USB-C
  connector's through-hole features need a separate line item from regular
  surface-mount assembly. The verified Amphenol CM5 connector is SMT and does
  not belong in this through-hole check.
  <br>*(Replaced 2026-08-01, kept here for history: the old plan was
  "machine-assemble the small surface-mount parts; hand-solder the
  connectors and through-hole parts.")*
- **No screen output.** No HDMI port (cut to reduce design complexity —
  two fewer sets of matched wire pairs to route). Remote login over WiFi is
  the main way to use the board (free — WiFi is already built into the CM5).
  The debug port is the required backup for troubleshooting boot problems.
- **No Ethernet port, no extra USB ports, no audio.**
- **Power-over-Ethernet cut**, pushed to a future revision (that revision
  would replace the power-input section but keep the voltage converter).
- **Battery ruled out** — a 15-25W continuous power draw would drain any
  reasonable battery pack in a few hours. The device stays plugged into the
  wall, full stop.
- **Power input: USB-C with Power Delivery (a standard that lets a device
  ask a charger for a specific voltage).** The negotiation chip (**CH224A**,
  LCSC part C42459160, confirmed in stock — set by resistor values on its
  control pins, no software needed, works with PD3.0/2.0 and Quick Charge)
  requests **9V** (not 20V — the corrected power number doesn't need the
  higher voltage), set with a single 6.8k-ohm resistor. Chose CH224A over
  CH224K because CH224A's power-input pins can handle up to 32V versus
  CH224K's 13.5V, giving more safety margin for the protection stage. Two
  extra pins (CFG2/CFG3) are reserved for a possible CM5 control-bus
  connection and may float in the fixed-resistor configuration. The software
  can check which voltage actually got negotiated and monitor live current
  during testing — this comes essentially for free with the resistor-based
  setup. The VBUS pin must be connected directly to the VHV pin per the
  reference design (easy to forget when drawing the schematic). No special
  "e-marker" chip needed since we're well under the 20V/60W threshold that
  requires one. The CH224A only negotiates and passes voltage through
  unchanged — it doesn't convert or regulate voltage itself; its "power
  good" pin just reports whether negotiation succeeded. The board refuses
  to run on plain 5V-only chargers (avoids weird brownout bugs). Backup
  plan if this gets complicated: switch to a plain USB-C connector with a
  standard 5.1V/5A charger, no negotiation.
  **USB-C connector: TYPE-C-31-M-12** (HRO Electronics, LCSC **C165948**),
  picked 2026-08-09 (Session 7) — 12-pin mid-mount receptacle, 5A/20V,
  CC1/CC2 for PD, USB 2.0 data pairs (DP1/DN1, DP2/DN2, no SuperSpeed
  needed). Through-hole mounting legs, board-edge-mount footprint. See
  Session 7 note above for the full reasoning.
  Voltage converter: **MP2329GG-Z** (from MPS, LCSC part C5349327,
  confirmed in stock) — accepts 4.5-24V in, outputs an adjustable 0.6-13V,
  rated for 6.5A continuous / 7.5A peak, small QFN-11 package. This is the
  only part in the chain that actually converts power — it steps the
  negotiated 9V down to the 5V/5A main power rail (the "backbone" that
  feeds everything else). The 6.5A rating is a ceiling; actual draw is
  around 2.6A given the corrected ~13W budget — well under half its
  capacity. The 5V-output resistor values (from the datasheet): R1 =
  40.2k ohms, R2 = 5.49k ohms, C4 = 33pF, inductor = 3.3µH — still need to
  confirm these exact parts are currently in stock (open item).
- **Input protection — simplified for the first revision (2026-09-07).**
  The TPS25947 eFuse has been removed from the schematic because it adds
  complexity that is not justified for this first board. The earlier eFuse
  choice and fuse → TVS → eFuse topology are historical decisions, not the
  current implementation. Retain and document only the protection parts that
  remain in the schematic after the simplified power path is finalized.
- **Handling weak chargers:** the negotiation chip's status output lights
  an LED at minimum (so you can see if a weak charger is connected);
  optionally also wired to a CM5 input pin so software can check the
  wattage. No automatic power-limiting based on this in the first version.
- **CM5 version: with built-in storage** (flashed once over USB using a
  jumper wire trick called nRPIBOOT). Decided against the microSD-card
  version — that would add a connector and a removable part that could fail,
  for a device that's supposed to be a sealed, finished unit. The small cost
  savings weren't worth it this late in the schedule.
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

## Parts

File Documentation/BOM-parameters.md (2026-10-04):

# BoM Parameter Inventory

Source: `Hardware/Schematics & PCB/BOM.BomDoc`  
BoM saved: 2026-09-28 14:35:59  
Catalog records: 29

This is a direct inventory of the BoM file. It does not inspect the schematic
documents. Designator and quantity values are resolved live by Altium and are
not stored in the `BomDoc` catalog records.

## Configured visible BoM columns

1. Line #
2. Comment
3. Description
4. Designator
5. Quantity
6. Source
7. Name
8. Manufacturer 1
9. Manufacturer Part Number 1
10. Manufacturer Lifecycle 1
11. Supplier 1
12. Supplier Part Number 1
13. Supplier Unit Price 1
14. Supplier Subtotal 1

## Catalog parameters

All records have:

- Item type: `Automatic-NonVault`
- Status: `Unknown`
- Source: `LCSC`
- Component kind: `Standard`
- Empty fields: `Note`, `Line Number`, `Ibis Model`, `PCB3D`, `Pin Info`,
  `Signal Integrity`, `Simulation`, and `Custom Parameters`

| # | Name | Value | Comment | Description | Footprint | Library / reference |
|---:|---|---|---|---|---|---|
| 1 | C466768 | 100nF | C0603X7R104K250NT | C0603X7R104K250NT | C0603 | C466768.SchLib / C0603X7R104K250NT |
| 2 | C5349327 | — | MP2329GG-Z | MP2329GG-Z | QFN-11_L2.0-W2.0-P0.50_MP2384CGG-Z | C5349327.SchLib / MP2329GG-Z |
| 3 | C15849 | 1uF | CL10A105KB8NNNC | 1uF ±10% 50V X5R 0603 ceramic capacitor | C0603 | C15849.SchLib / CL10A105KB8NNNC |
| 4 | C45783 | 22uF | CL21A226MAQNNNE | 22uF ±20% 25V X5R 0805 ceramic capacitor | C0805 | C45783.SchLib / CL21A226MAQNNNE |
| 5 | C14663 | 100nF | CC0603KRX7R9BB104 | 100nF ±10% 50V X7R 0603 ceramic capacitor | C0603 | C14663.SchLib / CC0603KRX7R9BB104 |
| 6 | C1671 | 47pF | CL10C470JB8NNNC | 47pF ±5% 50V C0G 0603 ceramic capacitor | C0603 | C1671.SchLib / CL10C470JB8NNNC |
| 7 | C21120 | 220nF | CL10B224KA8NNNC | 220nF ±10% 25V X7R 0603 ceramic capacitor | C0603 | C21120.SchLib / CL10B224KA8NNNC |
| 8 | C48543706 | 33pF | TCC0603COG330F500CT | 33pF ±1% 50V C0G 0603 ceramic capacitor | C0603 | C48543706.SchLib / TCC0603COG330F500CT |
| 9 | C6782225 | — | 10164227-1001A1RLF | 100-position 0.4mm board-to-board connector | CONN-SMD_100P-P0.40_10164227-1001A1RLF | C6782225_Part 1.SchLib / 10164227-1001A1RLF |
| 10 | C6782225 | — | 10164227-1001A1RLF | 100-position 0.4mm board-to-board connector | CONN-SMD_100P-P0.40_10164227-1001A1RLF | C6782225_Part 2.SchLib / 10164227-1001A1RLF |
| 11 | C5182313 | — | CSI Connector | 22-position 0.5mm FFC/FPC connector | FPC-SMD_22P-P0.50_FH55-22S-0.5SH | C5182313.SchLib / FH55-22S-0.5SH |
| 12 | C151251 | — | TVS | 21.5V clamp, 28A TVS diode, DO-214AA | SMB_L4.6-W3.6-LS5.3-RD | C151251.SchLib / SMBJ12A_C151251 |
| 13 | C354897 | — | Fuse | 3A surface-mount fuse, 1206 | F1206 | C354897.SchLib / 1206T3A63V |
| 14 | C2770993 | 6.8k | CQ03WAJ0682T5E | 6.8kΩ ±5% 100mW 0603 resistor | R0603 | C2770993.SchLib / CQ03WAJ0682T5E |
| 15 | C23186 | 5.1K | 0603WAF5101T5E | 5.1kΩ ±1% 100mW 0603 resistor | R0603 | C23186.SchLib / 0603WAF5101T5E |
| 16 | C25803 | 100k | 0603WAF1003T5E | 100kΩ ±1% 100mW 0603 resistor | R0603 | C25803.SchLib / 0603WAF1003T5E |
| 17 | C25818 | 453k | 0603WAF4533T5E | 453kΩ ±1% 100mW 0603 resistor | R0603 | C25818.SchLib / 0603WAF4533T5E |
| 18 | C723484 | 22.1k | RT0603BRD0722K1L | 22.1kΩ ±0.1% 100mW 0603 thin-film resistor | R0603 | C723484.SchLib / RT0603BRD0722K1L |
| 19 | C54102278 | 5.49k | FRQ0603F5491TS | 5.49kΩ ±1% 100mW 0603 resistor | R0603 | C54102278.SchLib / FRQ0603F5491TS |
| 20 | C12447 | 40.2k | 0603WAF4022T5E | 40.2kΩ ±1% 100mW 0603 resistor | R0603 | C12447.SchLib / 0603WAF4022T5E |
| 21 | C455280 | — | TS-1088R-02026 | SPST tactile switch, 3.9mm × 2.93mm | SW-SMD_L3.9-W3.0-P4.45 | C455280.SchLib / TS-1088R-02026 |
| 22 | C42459160 | — | PD | CH224A USB-PD receiver controller | ESSOP-10_L4.9-W3.9-P1.0-LS6.0-TL-EP | C42459160.SchLib / CH224A |
| 23 | C311983 | — | TPS54302DDCR | Adjustable 3A buck regulator, TSOT-23-6 | SOT-23-6_L2.9-W1.6-P0.95-LS2.8-BL | C311983.SchLib / TPS54302DDCR_C311983 |
| 24 | C7461350 | 6.8uH | CXP0530-6R8M-AG(6.8uh) | 6.8uH ±20% molded inductor | IND-SMD_L5.7-W5.2 | C7461350.SchLib / CXP0530-6R8M-AG_6.8UH |
| 25 | C19268654 | 3.3uH | CYA1250-3.3UH | 3.3uH ±20% molded inductor | IND-SMD_L13.8-W12.8 | C19268654.SchLib / CYA1250-3.3UH |
| 26 | C51118 | — | AP2112K-3.3TRG1 | 3.3V fixed SOT-25-5 LDO | SOT-25-5_L2.9-W1.6-P0.95-LS2.8-BL | C51118.SchLib / AP2112K-3.3TRG1 |
| 27 | C514175 | — | UART | 3-position 1.25mm right-angle connector | CONN-TH_SM03B-GHS-TB-LF-SN | C514175.SchLib / SM03B-GHS-TB_LF_SN |
| 28 | C165948 | — | TYPE-C-31-M-12 | 16-position USB-C receptacle | USB-C_SMD-TYPE-C-31-M-12_1 | C165948.SchLib / TYPE-C-31-M-12 |
| 29 | C601195 | — | 91302-42-067RDM | 67-position 0.5mm right-angle connector | CONN-SMD_91302-32-067RDM | C601195.SchLib / 91302-42-067RDM |

## Verified CM5 connector status

Catalog records 9 and 10 are approved as-is. They represent `CN1` and `CN2`,
the two required Amphenol `10164227-1001A1RLF` / LCSC `C6782225` CM5
connectors. Both schematic symbols contain 100 unique physical pins, and both
link to the verified 100-pad, 0.40 mm-pitch manufacturer-matching footprint.
No component, symbol, or footprint change is required; both instances are
ready for placement and routing.

## BoM document settings

- Currency: USD
- Production quantity: 1
- Include PCB parameters: yes
- Include database, vault, cloud, and document parameters: no
- Risky supplier solutions filtered: yes
- Designator grouping: no
- Grouping checks: Description and Footprint enabled; Comment and Value disabled
- Manufacturer-link parameters: none
- Favorite suppliers: none
- Supplier pricing and part-choice data: absent

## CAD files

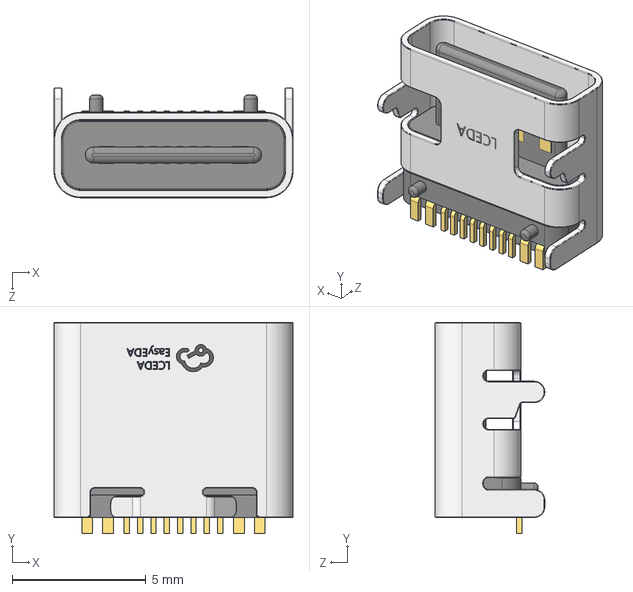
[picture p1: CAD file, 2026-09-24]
Hardware/Component Libraries/Power/STEP/C165948.step
8.94 x 7.90 x 4.10 mm

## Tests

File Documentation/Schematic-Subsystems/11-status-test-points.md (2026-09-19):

# 11 — Status Indicators and Test Points

Last updated: 2026-09-18

## Purpose

Provide safe measurement and visible diagnostic access during initial power-up,
CM5 flashing, boot, camera bring-up, and Hailo bring-up.

## Current status

**Rough draft.** The need for diagnostic access is confirmed. Visible main
power and PD-negotiation indicators are planned. Additional per-subsystem LEDs
and physical test-point package choices can be decided later.

## Confirmed bring-up philosophy

- Power and test one section at a time.
- Intended sequence: empty board/power system → CM5 → USB flashing → eMMC boot
  and UART → Wi-Fi/SSH → camera → Hailo.
- Status circuits must not significantly load power-good, reset, clock, or
  other boot-critical signals.
- High-speed PCIe, CSI-2, and USB test access must not create uncontrolled
  routing stubs.

## Planned minimum test access

- Multiple ground probe points.
- Negotiated/input supply after the USB-PD section.
- `5V_MAIN`.
- `3V3_HAILO`.
- `3V3_CAMERA`.
- Hailo enable/load-switch control.
- Hailo `PERST#`.
- `nRPIBOOT`.
- CM5 reset/power-control signal.
- Programming-port VBUS presence/sense.
- UART TX and RX through the debug connector.

## Planned indicator functions

- Main board/5 V power present.
- Successful USB-PD negotiation using the CH224A status signal.
- **Potential task:** add low-current rail-presence LEDs in parallel with
  `5V_MAIN`, `CM5_3.3V`, `3V3_HAILO`, and `3V3_CAMERA`, each with its own
  series current-limiting resistor. These show rail presence, not load margin
  or correct connection of every power pin.
- **Potential task:** consider buffered `LED_nPWR` or `LED_nACT` indication
  only if CM5 power-state or activity feedback is desired. Neither signal is
  needed for simple power-rail indication.
- Optional local-rail indications where they will not compromise regulation or
  create misleading results.
- Recovery/activity indication only when supported by a safe, reviewed signal.

## Definition of done

- A multimeter and oscilloscope can reach every major rail safely.
- Sequencing between `3V3_HAILO` and `PERST#` can be measured directly.
- Flash/recovery control states can be probed.
- LEDs have explicit current-limiting resistors.
- No indicator overloads or changes a critical signal state.
- High-speed interfaces remain free of unnecessary test stubs.

## Bring-up measurements to record later

- Input voltage before and after PD negotiation.
- `5V_MAIN` startup, ripple, and load behavior.
- `3V3_HAILO` startup time and reset-release delay.
- `3V3_CAMERA` voltage and regulator temperature.
- CM5 current during recovery and normal boot.
- UART boot log and PCIe/camera detection results.

## References

- `Documentation/Research MD/programming.md`.
- `Documentation/Research MD/power-design-explainer.md`.
- Project bring-up sequence in `Documentation/documentation.md`.

## Session notes

- 2026-09-18: Initial status/test-access draft created.

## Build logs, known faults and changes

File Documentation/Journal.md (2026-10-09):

# Journal — Wireless Watchdog: CM5 Carrier Board

An ongoing, append-only log of verified project decisions and dated work
records. **This journal is the source of truth for verified information.**
`documentation.md` is the daily working summary and active-blocker list, and
the schematic-subsystem files hold implementation detail. Later entries
supersede earlier entries when the design or verified CAD state changes.
Historical mentions of `CLAUDE.md` below describe an older documentation
workflow and do not make that file a current authority.

---

## 2026-07-30 — Power system correction + notes cleanup

Folded into CLAUDE.md the same day. See CLAUDE.md's "Session log" (Session
3) for the summary — corrected the power budget (~20-23W → ~13W), switched
the power negotiation chip (CH224K → CH224A) and voltage converter
(TPS54560 → MP2329GG-Z), and fixed an earlier mistake where the Hailo-8L's
power rail was briefly (and wrongly) called okay for a simple linear
regulator, before double-checking the datasheet confirmed the 6.6W/2A max
number already in CLAUDE.md was correct all along — it still needs a real
switching converter.

Also merged `documentation.md` and `status.md` into CLAUDE.md (nothing new
in either, both deleted) and switched from separate dated session-log files
to this one running Journal.md.

---

## 2026-08-01 — Timeline pushed back, assembly plan reversed, GitHub sync gap found

Folded into CLAUDE.md the same day. See CLAUDE.md's "Session log" (Session
4) for the summary. Raw notes below for details that didn't need to go into
the main file.

**Timeline pushed back.** The class instructor (Design Project III) will
review the board before it gets ordered. Class starts Sep 2; budgeting
about 2 weeks after that for review and fixes, so the board order moves
from Aug 29-31 to **around Sep 16**. The internal work deadlines (schematic
done Aug 9, layout done Aug 23) are staying the same on purpose — the extra
time is a buffer for review and fixes *after* layout is finished, not extra
time for the design work itself. Worked out what this means down the line:
bare circuit board back around Sep 23-25, assembled board back around
Sep 30-Oct 6 (parts take extra time to source), so a realistic
finished-and-working board is mid-to-late October, not the "late
September" target in CLAUDE.md's project summary. Flagged as an open,
unresolved tension with the recruiting deadline — the decision to push the
timeline back was made on purpose (a correct board matters more than
hitting the calendar date), but nobody has separately checked whether
mid-October still works for recruiting timing.

**Assembly plan reversed.** Decided to have JLCPCB machine-assemble
everything, including the connectors and other through-hole parts — no
hand-soldering step at all. This removes the risk of a bad hand-soldered
joint (bad connections, solder bridging between pins, parts standing up at
an angle) but does **not** remove the risk of a wrong part footprint — a
perfectly, professionally soldered wrong footprint is still a dead board.
Realized during the discussion that the original "hand-solder the
connectors" plan was never really doable anyway, given how tiny and
closely-spaced the DF40 connector's pins are — so this is more of a
correction than a real tradeoff. Still to check: does JLCPCB's assembly
quote need a separate line item for through-hole parts (DF40, M.2 socket,
maybe the USB-C connector) versus regular surface-mount assembly?

**USB-C connector added to the schematic, no exact part picked yet.** First
part placed in the power-input section. The protection chip is still the
oldest open item (unchanged since 2026-07-25) — noted that finishing the
protection chip, the USB-C connector part, and the Hailo-8L's local
converter should all happen *before* placing more parts in the power
section, to avoid designing around gaps.

**Simulation plan discussed and scoped down.** Decided against simulating
every part of the power system. LTspice (the simulation tool) is only used
for analog power behavior (voltage, current, stability) — not for checking
PCIe/camera signal quality, which is a separate, later step done in Altium
after the board layout exists. Two simulations picked as worth doing: the
MP2329 converter (9V→5V, which finishes checking an open question about the
resistor values, checks stability, and tests how it responds to a sudden
jump in power demand from CM5 idle to Hailo-8L full load) and the eventual
Hailo-8L local converter, once picked — both using the manufacturer's own
simulation models. Everything else (the CH224A pass-through chip, the
camera's linear regulator, the sequencing delay circuit) was judged not
worth simulating. Decided to finish picking the protection chip and local
converter first, then run both simulations back-to-back, rather than
simulating now and having to redo it later with different parts.

**GitHub sync gap found and fixed.** Partway through this session,
CLAUDE.md and Journal.md turned out to be 6 days out of date (still showing
"Last updated: 2026-07-25" even though Session 3 happened on 2026-07-30)
when re-uploaded to a claude.ai session for timeline planning — meaning an
earlier timeline discussion in that session was based on stale information
about the protection chip and converter status. Root cause: the GitHub
connection in a claude.ai Project is **read-only** — it only pulls files
from GitHub into the conversation, it can't push changes back out. There's
no way to push from the claude.ai web interface. Actual pushes require
Claude Code, plain git commands, or editing files directly on GitHub.com.
Added a rule to CLAUDE.md to push documentation to GitHub at the end of
every work session, instead of "whenever."

**Converting LCSC parts to Altium footprints, settled separately (not
folded into CLAUDE.md — this is a tooling choice, not a hardware
decision).** After a long research thread, decided: don't build a custom
converter, and don't bother with third-party tools from GitHub either
(like EasyEDALoader), since only about 2 parts (CH224A, the UMAX M.2
socket) are LCSC-only without an official design-software library entry
(name-brand library services cover everything else in the parts list by
part number). EasyEDA's own built-in Altium export feature (File → Export →
Altium Designer, confirmed free — the design tool itself has no paywalled
features, only cloud storage/support are paid) is the answer for those two
parts: export to a scratch project, then use `Design → Make Schematic/PCB
Library` in Altium. Checking the footprint against the real part (1:1
printout, comparing against the manufacturer's drawing) is still required
either way — this shortcut saves drawing time, not checking time, and
doesn't change the required fit-check for the CM5/M.2 connectors already
locked into CLAUDE.md.

---

## 2026-08-08 — Input protection stage closed out (TVS, eFuse, backup fuse)

Folded into CLAUDE.md the same day. See CLAUDE.md's "Session log" (Session
5) and "Decisions locked → Input protection" for the summary. Raw notes
below.

**Started from a basic question:** confirmed the input-protection stage
actually needs three separate parts — TVS, eFuse ("protection chip" in
earlier sessions' language), and a plain backup fuse — not just the
protection chip that was already being tracked. The backup fuse had never
actually made it onto the Outstanding list despite being named in
"Decisions locked" since Session 2; that gap is now closed.

**Read what was already on hand first.** No datasheet in `Datasheets/`
covers any of the three parts — confirmed by listing the folder (only
CM5, Hailo-8L, CH224A, and MP2329 datasheets exist). Pulled the CH224A and
MP2329 datasheets specifically to ground the voltage ceiling the
protection stage has to survive under: CH224A operates 4-30V input,
MP2329's absolute max input is 26V. That 26V number is the real ceiling —
whatever gets picked has to clamp/limit below it.

**Picked all three parts**, each backed by a real, stock-checked LCSC part
number:
- TVS: **SMBJ12A** (Littelfuse, LCSC C151251) over SMAJ12A (smaller
  package, less pulse-energy margin — not worth it given the connector
  gets plugged/unplugged a lot during bring-up).
- eFuse: **TPS25947** (LCSC C3662799) over TPS25940 (LCSC C2867756) — now
  that the design requests 9V not 20V, TPS25940's 18V rating isn't
  actually tight anymore, but TPS25947 still wins on lower on-resistance
  and real reverse-polarity blocking (back-to-back FETs) for similar cost.
- Backup fuse: **1206T3A63V** (Walter Elec, LCSC C354897, 3A/63V,
  fast-acting, 18.4k in stock) over a PTC resettable fuse — deliberately
  picked the one-time type instead of a self-healing PTC, because this
  fuse's whole job is to be the last-resort signal that the *active*
  protection (the eFuse) already failed. A PTC that quietly resets doesn't
  force that failure to actually get noticed and fixed.

**Found and fixed a topology mistake mid-discussion.** The first pass at
ordering the three parts was TVS → fuse → eFuse (TVS closest to the
connector, for best transient response). Caught during discussion: TVS
diodes have a known failure mode of failing *shorted* under an
over-energy event. If the fuse sits after the TVS, a shorted TVS shorts
VBUS straight to ground without the fuse — which only sees current in the
path toward the eFuse — ever tripping. Reordered to **fuse → TVS →
eFuse**, so the fuse also backs up a shorted TVS, not just a shorted
eFuse. Traded a few mm of extra trace length between the connector and
the TVS clamp point (marginally worse transient response) for that
coverage.

**Not yet resolved:** this reordering was reasoned from first principles,
not copied from a reference design — same caution that already applies to
the DF40 connector pin layout. Should be checked against the Spectre RM
DevBoard's power-input section (already on hand, has its own surge
protection/two-converter input stage) before being treated as final.

---

## 2026-08-09 — USB-C connector part picked (TYPE-C-31-M-12 / C165948)

Folded into CLAUDE.md the same day. See CLAUDE.md's "Session log" (Session
7) and "Decisions locked" for the summary. Raw notes below.

**Checked the new datasheet (`Datasheets/C165948.pdf`) against what the
connector actually needs to cover**, rather than just trusting the part
number: CC1/CC2 both present (required for CH224A's PD negotiation and
cable-orientation detection), VBUS/GND spread across multiple pins, and
DP1/DN1 + DP2/DN2 (a mirrored pair, no SuperSpeed pins) for the USB 2.0
debug/flashing line — matches the plan, since no USB 3.0 is used anywhere
on this board. SBU1/SBU2 are broken out on the part but not needed
(alt-mode/audio only) — left no-connect.

**Rating check:** part is rated 5A/20V. At the fixed 9V PD request and the
~13W power budget, actual draw is ~1.5A — well under the 5A rating, and
20V comfortably covers the 9V request. Not the bottleneck anywhere in the
chain.

**Mechanical finding, ties back to an open item:** the datasheet's bottom
view shows through-hole mounting legs (2× Ø0.50 holes), not a pure-SMT
shell. This directly answers part of the "confirm through-hole shell"
question that had been sitting open since Session 4 — now three parts
(DF40, M.2 socket, USB-C connector) are confirmed through-hole and need
the JLCPCB assembly-quote question resolved together. Also noted the part
is a board-edge-mount footprint (datasheet flags "PCB EDGE" against one
side) — true of any USB-C receptacle, not a special property of this part,
but worth remembering when placing it so the board outline lines up.

**Also revisited the power-distribution flow itself** while going through
this (not a new decision, just confirmed out loud): PD negotiation (CH224A)
happens first since it only passes voltage through unchanged and doesn't
protect anything; the fuse → TVS → eFuse protection stage sits after it,
sized against the actual negotiated 9V rather than an unknown worst-case
input; then the MP2329 converts down to the 5V rail. One flow, not
parallel paths.

Next: Bill starts the footprint for C165948. Then the Hailo-8L's local
converter (5V→3.3V, ≥2A) is the next open item — the last unpicked part in
the power chain.

---

## 2026-08-10 — Main power path and USB-C/CH224A schematic decisions

Started the power schematic from the USB-C input and resolved the naming and
topology before adding the downstream regulators.

**Fixed names.** The USB-C connector pins are named `VBUS`. The project net
before the fuse is `USB_VBUS`; the first fuse is component `F1`; the net after
F1 is `FUSED_VBUS`. FUSED_VBUS is a node, not another component. The CH224A
pin names remain exactly as in its datasheet: pin 1 is `VHV`, pin 8 is `VBUS`,
pin 6 is `CC2`, pin 7 is `CC1`, pin 4 is `DP`, and pin 5 is `DM`.

**Main power path:** USB-C VBUS pins → USB_VBUS → F1 → FUSED_VBUS. From
FUSED_VBUS, the CH224A VHV and VBUS pins are tied together, the TVS is a
shunt to ground, and the TPS25947 input is connected. The TPS25947 output
feeds the MP2329, whose output is `5V_MAIN`. The CH224A is a PD controller
on the VBUS node, not a series power converter or a separate PD output stage.

**CH224A configuration.** Use the CH224A/CH224Q reference schematic, not the
CH224D drawing. A 6.8k ohm resistor from CFG1 to ground requests 9V. CFG2
and CFG3 may remain floating when I2C control is not used. CC1 and CC2 stay
separate and connect to the corresponding USB-C pins. If BC1.2 detection is
not used, the CH224A DP and DM pins are no-connect; the connector USB 2.0
D+ and D- remain separate signals for the CM5 flashing/debug connection.

**C165948 pin mapping.** Tie A4/A9/B4/B9 together for VBUS; tie A1/A12/B1/B12
together for ground; tie A6/B6 for USB D+; and tie A7/B7 for USB D-. Leave
SBU1 (A8) and SBU2 (B8) no-connect. EH1 through EH4 are the connector
shell/mounting contacts and connect to ground for this schematic.

**Repository boundary.** The Altium directory was removed from the GitHub
documentation repository. The authoritative Altium project remains at
`C:\Users\Bill\Desktop\Bill's Folder\Altium\Project Watchdog` and is not
part of the Obsidian documentation checkout. GitHub authentication uses a
Personal Access Token in place of the account password; the token must not
be stored in project files or documentation.

Next: finish the power schematic from the locked FUSED_VBUS node through the
eFuse and MP2329, then verify the CH224A and MP2329 reference circuits before
adding the local Hailo and camera rails.

---

## 2026-08-16 — Programming plan, current datasheets, and documentation cleanup

Defined how the CM5 will be programmed and recovered. The carrier board does
not contain a separate firmware microcontroller: the CM5 is flashed through
USB boot mode, with the operating system and Watchdog software installed on
the CM5's onboard eMMC. The normal boot chain is CM5 ROM → EEPROM bootloader
→ eMMC → Linux → systemd → Watchdog services.

Created `Research MD/programming.md`, covering factory eMMC flashing with
`rpiboot`, normal SSH/Wi-Fi development, debug UART use, `nRPIBOOT` recovery,
reset/power control, and the PCB connections required for bring-up. The
programming design still needs a final choice between a dedicated USB
programming connector and a factory pogo/test-pad connection.

Re-read the current power-chain datasheets from the local Obsidian project
folder and copied all eight into `Documentation/Datasheets`, including the
current `TPS259470ARPWR` eFuse datasheet plus the capacitor and resistor
datasheets. The main documentation file was renamed from `CLAUDE.md` to
`documentation.md`.

Tomorrow: read `Research MD/programming.md`, then connect the CH224A PD request
node through the fuse, TVS, TPS259470ARPWR eFuse, and MP2329 buck converter
using the current datasheets as the authoritative technical references. Verify every eFuse pin,
required passive, power net, and ground connection before continuing to the
local rails.
---

## 2026-09-03 — CM5 connector wiring and bring-up architecture

Clarified the physical and software architecture for the CM5 carrier board
before continuing the schematic. The CM5 is the complete computer: processor,
Linux, bootloader, onboard eMMC, Wi-Fi, Bluetooth, USB, UART, I2C, GPIO, and
PCIe are already inside the module. The carrier board does not need a separate
MCU or bridge chip for the planned design; it routes the required CM5 signals
through the two Amphenol 100-pin board-to-board connectors.

Locked the bring-up connections:

- One USB-C connector is dedicated to power. Its path is USB-C power input →
  protection/PD circuitry → 9V internal rail → 5V regulator → CM5 5V pins.
- A second USB-C connector is dedicated to CM5 programming and recovery. It
  routes USB 2.0 D+/D− to the CM5 and lets a host computer expose the CM5's
  onboard eMMC as USB mass storage for Raspberry Pi OS flashing.
- Pin 93 (`nRPIBOOT`) gets an accessible jumper or pushbutton to ground. This
  selects USB recovery mode during power-up; it does not provide power or do
  the flashing itself.
- A separate three-pin UART debug connector exposes TX, RX, and GND for an
  external 3.3V USB-to-UART adapter. UART is the early-boot diagnostic path;
  USB programming and UART are separate physical connections.

The full CM5 variant has onboard eMMC, so it does not need a physical SD-card
socket. Initial bring-up will be staged: power and CM5 only; USB flash; eMMC
boot; UART verification; Wi-Fi/SSH; camera; then Hailo-8L.

The communication roles were separated clearly. Camera video uses CSI-2;
camera configuration uses I2C; Hailo-8L communication uses PCIe; UART is for
the CM5 debug console; SPI is not currently needed. Hardware routing comes
first, but Linux Device Tree configuration, drivers, HailoRT, camera support,
and application software are still required after the board is assembled.

Before committing to the custom Hailo connection, the Hailo-8L currently
installed on the Raspberry Pi M.2 HAT+ should be tested on a Raspberry Pi 5.
That test verifies the module, power, PCIe communication, firmware, HailoRT,
and inference software. It does not fully validate the custom CM5 carrier
board's PCIe routing, because the Raspberry Pi AI Kit is commonly configured
for PCIe Gen 3 while the CM5 carrier board is designed for supported PCIe Gen
2 x1 operation.

Ethernet was considered and remains out of scope for this revision. Wi-Fi is
already built into the selected CM5, and Ethernet would require the MagJack,
ESD protection, four 100-ohm differential pairs, and additional board area.

---

## 2026-09-07 — Simplified first revision and connector schematic work

Removed the TPS25947 eFuse from the first board revision. The eFuse adds
design and bring-up complexity that is not justified for this iteration. The
previous eFuse selection and fuse → TVS → eFuse discussion remain above as
historical research; they no longer describe the active schematic.

The active schematic work is now the CM5 interface: the two 100-pin CM5
connectors and the M.2 socket for the Hailo-8L M+B-key card. This includes the
CM5-to-M.2 PCIe connection, the associated power and ground connections, and
the required control signals.

The board retains UART for early-boot debugging: CM5 pin 55 (`GPIO14` /
`UART0_TX`) connects to the debug adapter's RX input, and CM5 pin 51
(`GPIO15` / `UART0_RX`) connects to the adapter's TX output. CM5 pin 93
(`nRPIBOOT`) connects to an accessible jumper or pushbutton to ground for USB
recovery during power-up. CM5 pins 94 and 96 (`CC1` and `CC2`) remain
intentionally unconnected because the separate CH224A power-input circuit owns
its USB-C CC signals.

**Connector 1 GPIO reference completed.** CM5 pin 78 (`GPIO_VREF`) is tied to
the 3.3 V output net from pins 84 and 86. Pin 78 is a reference input, so this
sets the CM5 GPIO bank to 3.3 V signaling; it is not another 3.3 V supply
output. The next schematic task is the second 100-pin CM5 connector. Detailed
decisions about the remaining pin uses and wiring are deferred until that
sheet is in place.

---

## 2026-09-08 — Hailo-8L M.2 custom-symbol pinout locked

Verified the custom M.2 socket assignment against the Hailo-8L M.2 Key B+M
ET Module Data Sheet Rev. 4.0, section 2.2, and the current Raspberry Pi CM5
datasheet. The board uses the UMAX `91302-42-067RDM` 67-contact M-key socket
(LCSC `C601195`); the Hailo-8L B+M-key module fits this socket.

The custom symbol is grouped by function as follows:

- Power: pins 2, 4, 70, 72, and 74 are `3V3_HAILO`. Ground: pins 3, 27,
  33, 39, 45, 51, 57, 71, and 73 are `GND`.
- PCIe lane 0: pin 41 `PETn0` → CM5 pin 118 `PCIe_RX_N`; pin 43 `PETp0`
  → CM5 pin 116 `PCIe_RX_P`; pin 47 `PERn0` → CM5 pin 124 `PCIe_TX_N`;
  pin 49 `PERp0` → CM5 pin 122 `PCIe_TX_P`.
- Clock/control: pin 53 `REFCLKn` → CM5 pin 112 `PCIe_CLK_N`; pin 55
  `REFCLKp` → CM5 pin 110 `PCIe_CLK_P`; pin 50 `PERST#` → CM5 pin 109
  `PCIe_nRST`; pin 52 `CLKREQ#` → CM5 pin 102 `PCIe_CLK_nREQ`. Pin 54
  `PEWAKE#` can connect to CM5 pin 104 `PCIE_nWAKE`, but wake is currently
  unsupported by CM5 software and this signal may be left unconnected.
- PCIe lane 1 is deliberately unused because CM5 exposes only x1: pins 29
  `PETn1`, 31 `PETp1`, 35 `PERn1`, and 37 `PERp1` get explicit no-connects.
- Configuration contacts describe the module: pins 1, 21, and 75 are the
  module-grounded configuration bits and pin 69 is the module's NC
  configuration bit. They are detection signals, not extra power grounds;
  leave the carrier side open unless module-type detection is implemented.
- All remaining M-key socket contacts are unused for this Hailo module and
  get explicit no-connect markers. Pins 59–66 are absent because they form
  the M-key notch. The imported `C601195.SchLib` reports 68 pins, so its one
  extra pin must be checked against the connector drawing as a shield or
  mechanical contact before it is tied to ground.

**Power wiring still required.** `5V_MAIN` must feed a local 5 V-to-3.3 V
switching converter rated for at least 2 A, then the sequenced/switched
`3V3_HAILO` rail must connect to all five M.2 power pins. Raw 5 V must never
be connected to the Hailo M.2 socket. A separate camera branch is also still
unfinished: `5V_MAIN` must feed the selected camera regulator, and its
verified output rail(s) must connect to the CSI-2 camera connector power pins.
Confirm the exact camera module voltage requirements and connector pin map
before wiring that branch. Both local rails need nearby decoupling, test
points, and a common ground return.

> Later the same day, the component-selection portion of this open item was
> closed by the “Local Hailo and camera power rails selected” entry below.
> The exact camera was later locked to the standard Raspberry Pi Camera Module
> 3 by the 2026-09-28 reconciliation entry. Physical schematic wiring and Hailo
> reset sequencing remained open at this checkpoint.

The detailed pin table is recorded in
`Research MD/PCIe-x1-Differential-Pairs-Explainer.md`. No schematic-library
binary was modified during this documentation pass, and nothing was pushed.

---

## 2026-09-08 — Repository and design-state audit

**Status: Findings and proposed work; no architecture decision superseded.**

Reviewed the current documentation, Git state, Altium project membership, CAD
file inventory, and schematic previews. The audit's resolved observations are
preserved in this entry; its still-open release requirements are maintained at
the top of `documentation.md`.

The audit confirmed that the two CM5 connector-library corrections in the
root README remain the highest-priority release blockers. It also found that
there is no PCB layout document, both CM5 sheets remain largely unwired, the
tracked M.2 sheet is blank, and the new blank `Buck to M.2 & CSI.SchDoc` is
untracked and not included in the Altium project. The documented August layout
deadline and approximately September 16 order date are no longer credible.

The next decisions are to choose the Rev A scope, choose the authoritative
M.2/CSI sheet structure, finish the Hailo regulator and sequencing design,
define behavior before successful 9 V USB-PD negotiation, and select the exact
camera. Programming/recovery circuitry, mechanical constraints, PCB rules, and
manufacturing verification remain required before release.

No design choice was made on Bill's behalf. Existing local documentation,
library, history, and schematic changes were preserved. These documentation
edits are local only; nothing was committed or pushed.

---

## 2026-09-08 — Local Hailo and camera power rails selected

**Confirmed:** keep two separate local branches from `5V_MAIN`. The Hailo-8L
has large and fast load changes, so its 3.3 V switching rail must not be shared
directly with the camera. The rails still share the upstream 5 V source and
ground, but separate regulation, local decoupling, and careful layout reduce
the noise and voltage-transient coupling into the camera supply.

The Hailo branch now uses Texas Instruments **TPS54302DDCR**,
JLCPCB/LCSC **C311983**. It is a 4.5 V to 28 V input, adjustable 3 A,
400 kHz synchronous buck in TSOT-23-6 and provides margin above the Hailo
module's documented 3.3 V/2 A maximum. For a 3.3 V output, the TI datasheet
starting values are 100 kΩ output-to-FB, 22.1 kΩ FB-to-ground, 47 pF across
the upper feedback resistor, 6.8 µH inductance, at least 10 µF ceramic input
decoupling, 0.1 µF BOOT-to-SW, and 44 µF effective ceramic output capacitance.
Use an inductor rated for at least 3 A RMS and preferably above 4 A saturation.
The IC has internal soft-start but no power-good output, so stable-rail versus
PCIe-reset sequencing remains unresolved by the regulator alone.

The camera branch uses the previously selected genuine Diodes Incorporated
**AP2112K-3.3TRG1**, JLCPCB/LCSC **C51118**, a fixed 3.3 V/600 mA LDO in
SOT-25-5. Use at least 1 µF X5R/X7R capacitors directly at its input and
output. JLCPCB showed 64,064 units in stock during this check; C311983 also
had healthy distributor availability. Stock is a dated snapshot and must be
checked again when the assembly order is prepared.

**Confirmed CSI power correction:** the standard Raspberry Pi 22-pin CSI
connector has one 3.3 V supply input on pin 22. It does not require a separate
1.8 V supply from the carrier. Camera Module 3 generates its lower internal
rails on the camera PCB. Raspberry Pi budgets approximately 250 mA for a
camera, or about 0.825 W at 3.3 V. The AP2112 dissipates approximately 0.425 W
at that load from 5 V, so it needs useful copper area and should not be assumed
to deliver its full electrical 600 mA rating continuously from 5 V without a
thermal check.

**Superseded:** the older note requiring external 1.8 kΩ camera I2C pull-ups.
The current CM5 datasheet states that SCL0 and SDA0 already have internal
1.8 kΩ pull-ups to `CM5_3.3V`. Do not fit another pair by default because the
parallel result would be approximately 900 Ω.

Documentation only was changed. No Altium binary was edited, and no commit or
push was requested.

---

## 2026-09-09 — M.2 and local-power documentation normalized

Placed each current decision in its intended long-term reference:

- `Research MD/PCIe-x1-Differential-Pairs-Explainer.md` is the detailed
  technical reference for the Hailo M.2 socket pins, lane directions, CM5 mapping,
  no-connects, and power contacts.
- `Research MD/power-design-explainer.md` is the detailed technical reference for
  the separate `5V_MAIN` → TPS54302 → `3V3_HAILO` and `5V_MAIN` → AP2112K →
  `3V3_CAMERA` branches.
- `documentation.md` holds the current design summary and session index, while
  this journal preserves the chronological decisions and resume checkpoint.
- The September 8 audit's Hailo-regulator selection was resolved without
  closing the remaining implementation work; current blockers are maintained
  at the top of `documentation.md`.

Next CAD work remains: draw and verify both regulator branches and their
required passives/decoupling, connect `3V3_HAILO` to M.2 pins 2, 4, 70, 72,
and 74, connect `3V3_CAMERA` to CSI pin 22, and ensure the Hailo rail is stable
before `PERST#` is released. No Altium binary was changed by this
documentation pass, and nothing was committed or pushed.

---

## 2026-09-18 — Schematic subsystem records and Rev A simplifications

**Confirmed:** Schematic V1 is now tracked in per-subsystem working notes under
`Documentation/Schematic-Subsystems/`. The standard Raspberry Pi Camera Module
3 is selected, using the normal Raspberry Pi 5-style camera cable and the
current 22-pin carrier connector.

The second programming/recovery USB-C port will reuse the existing HRO
`TYPE-C-31-M-12` receptacle (`C165948`) to reduce unique BOM items. Its circuit
remains electrically separate from the USB-PD power input: USB 2.0 device
wiring, appropriate CC termination, ESD protection, and safe VBUS sensing will
be used without tying host VBUS directly to `5V_MAIN`.

**Confirmed Rev A simplification:** omit both previously considered load
switches. TPS22965 (`C347592`) is not fitted on the Hailo branch, and TPS22918
(`C131941`) is not fitted on the camera branch. These are load switches, not
voltage regulators. TPS54302DDCR (`C311983`) remains the Hailo 5 V-to-3.3 V
buck regulator, and AP2112K-3.3TRG1 (`C51118`) remains the camera 5 V-to-3.3 V
LDO. Hailo power/reset timing will be verified using `3V3_HAILO` and `PERST#`
test access.

**Confirmed:** omit a CM5 `PWR_BUT` pushbutton from Rev A, retain the existing
`C15849` capacitor, leave M.2 `PEWAKE#` disconnected, and retain the three-pin
TX/RX/GND debug UART. A normally-open `nRPIBOOT` recovery pushbutton remains
required; its exact JLCPCB component is pending approval.

---

## 2026-09-18 — Hailo buck and intended camera LDO circuit drawn

> **Later correction:** the 2026-09-19 saved-CAD review found U3 pins 2–5
> connected incorrectly and the output capacitor missing. The camera portion
> below records the intended circuit and is not evidence of a completed fix.

The local M.2/Hailo TPS54302 buck circuit and the intended CSI-2 camera AP2112
LDO circuit were drawn. The camera regulator remains Diodes Incorporated
`AP2112K-3.3TRG1` (JLCPCB/LCSC `C51118`), whose `-3.3` ordering suffix fixes
the output at 3.3 V without feedback resistors. `VIN` and `EN` share
`5V_MAIN`, GND is connected normally, NC is intentionally open, and VOUT
creates `3V3_CAMERA` for camera-connector pin 22.

The intended AP2112 capacitors use the existing `C15849` library part: 1 µF,
50 V, X5R, 0603, one from VIN to GND and one from VOUT to GND. The selected
standard Raspberry Pi Camera Module 3 current still needs a final documented
check; 300 mA is retained as a thermal review case. At 300 mA, the SOT25 LDO dissipates about 0.51 W and has
an estimated 94°C junction rise using the datasheet's 184°C/W value; useful
copper and prototype thermal testing remain required.

The Hailo output network uses the final selected sourcing substitutions:
6.8 µH inductor `C7461350`, 100 kΩ upper feedback resistor `C25803`, 22.1 kΩ
lower feedback resistor `C723484`, 47 pF feed-forward capacitor `C1671`, two
22 µF output capacitors `C45783`, and 100 nF bootstrap capacitor `C14663`.

---

## 2026-09-19 — M.2 and CSI-2 connector wiring completed

The Hailo M.2 socket is now connected to the CM5 connector through PCIe Gen 2
x1: lane 0 TX/RX, reference clock, `PERST#`, and `CLKREQ#`, together with all
required `3V3_HAILO` and ground contacts. Lane 1, `PEWAKE#`, the unused module
configuration contacts, CM5 `PCIE_nWAKE`, and CM5 `PCIE_PWR_EN` remain
unconnected for Rev A. The M.2 module supplies its required transmit-side AC
coupling, so no duplicate series capacitors were added on the carrier.

The 22-pin CSI connector is also fully connected: four MIPI data pairs, one
MIPI clock pair, `SCL0`/`SDA0`, `CAM_GPIO0`/`CAM_GPIO1`, `3V3_CAMERA`, and all
ground contacts. No additional I²C pull-ups were added because the CM5 owns
the camera-bus pull-ups. Review found and corrected misleading friendly labels
in the imported CM5 connector symbol: the authoritative mapping is CM5 pins
115/117 for MIPI0 lane 0, 121/123 for lane 1, 127/129 for clock, 133/135 for
lane 2, and 139/141 for lane 3.

Both interfaces are schematically complete. Controlled-impedance rules,
differential-pair routing, intra-pair length tuning, continuous reference-plane
verification, and final FPC cable-orientation review remain PCB-layout tasks.

---

## 2026-09-19 — CM5 connector numbering and base audit corrected

Both placed Amphenol connector instances now contain 100 unique physical pin
designators numbered 1–100. `CN1` represents CM5 logical pins 1–100 and `CN2`
represents logical pins 101–200; their component designators distinguish the
two identical footprints. The prior documentation claiming CN1 pins 3–6,
9–12, and 15–20 were grounds was incorrect. They are Ethernet, fan, LED,
sync, and EEPROM-control signals and remain unused for Rev A.

Verified all 21 CN1 grounds and all 30 CN2 grounds are connected. Unused GPIOs
have no-connect markers; pins 51/55 remain for UART and pins 97/100 for camera
control. Pins 21, 76, 92, 95, and 99 are unused and still need explicit
no-connect markers; pin 93 remains reserved for `nRPIBOOT` recovery.

A potential later status task is to add resistor-limited rail-presence LEDs
for `5V_MAIN`, `CM5_3.3V`, `3V3_HAILO`, and `3V3_CAMERA`, plus buffered CM5
power/activity indication only if it provides useful diagnostics.

---

## 2026-09-19 — Schematic V1 closed and transferred to PCB

Completed the programming USB-C, `nRPIBOOT` recovery control, three-pin JST GH
UART, remaining intentional no-connects, and final component placement on the
schematic sheets. The unavailable 3.3 µH main-rail inductor `C19268642` was
replaced by stocked SHOU HAN `CYA1250-3.3UH` (`C19268654`), rated 20 A with
32 A saturation current; its dedicated PCB footprint was imported.

The Altium project compile/ECO completed with no reported errors or warnings,
and all schematic components were imported into `Watchdog PCB.PcbDoc`. The
active phase is now PCB layout, beginning with board outline/constraints and
major component placement before detailed routing.

---

## 2026-09-19 — Saved-CAD review reopens schematic corrections

**Confirmed findings; fixes open:** inspection of the four active schematic
sheets, saved PCB component/pad/net records, and transfer ECO found:

- U7 AP2112 physical pins 2–5 mapped incorrectly, including actual GND on
  main 5 V; camera output capacitor absent (C15 is input decoupling).
- C8/C9 output-side pads unconnected to the Hailo rail.
- USBC1 cable-ground groups unconnected despite grounded shell pads.
- CN1-93 nRPIBOOT open, with no implemented recovery control.
- No programming USB data ESD array in the active component inventory.

**Superseded:** the previous entry's blanket schematic/recovery/protection
completion claims. PCB transfer occurred, but no-error reporting was not
electrical sign-off. Documentation now prioritizes corrections before routing.
No schematic, PCB, library or BOM fixes were made, and ERC was not rerun.

**Proposed:** C4 C466768 → Basic C14663 and R1 C2770993 → Basic C23212.
Electrical parameters match or improve; R1's automotive qualification is not
retained. Availability/classification must be rechecked at order time.
Potential Economic assembly savings are approximately $6.14/order only if
both replaced types would otherwise incur Extended loading fees. No other
strictly equivalent Basic substitution was verified; four classifications
remain unresolved in the 27-type inventory.

**Open validation:** camera identity/load and LDO thermal margin; Hailo reset
startup/brownout timing; 27 W source versus simultaneous load and fuse margins;
CN3 footprint-name/mechanical compatibility; programming VBUS requirements;
ERC electrical types/no-connect handling and NetlistSinglePinNets=0; connector
geometry, FPC orientation, stackup and routing constraints. Clear rail names
are a proposed readability improvement. Power/signal LEDs remain optional.

Bill requested recording these findings. Updated the main status, subsystem
dashboard and affected subsystem notes. The still-open findings are maintained
in `documentation.md` and the affected subsystem records.

## 2026-09-20 — BOOT pushbutton selection

**Confirmed:** Bill requested changing the recovery-button choice to TE
Connectivity `3-1437565-0` (`FSM2JSMATR`), JLCPCB/LCSC `C86463`.
This supersedes the conversational recommendation of XKB `TS-1187A-B-A-B`
(`C318884`), which had not been implemented. TE specifies momentary OFF-(ON)
SPST operation, 160 gf force, 4.3 mm height, and 50 mA at 24 VDC. JLCPCB
lists a 6 x 6 mm four-pad SMT package and Extended classification.
Wire the switched contacts between CN1-93 (`nRPIBOOT`) and GND, retaining
the planned labeled test point and the CM5's internal pull-up.
Selection only: no Altium schematic or PCB edits were made. Verify the TE
drawing's contact pairing and land pattern before CAD implementation;
live stock and price were not verified.

Sources: [TE](https://www.te.com/en/product-3-1437565-0.html),
[JLCPCB](https://jlcpcb.com/partdetail/TEConnectivity-3_14375650/C86463).

## 2026-09-20 — Replacement BOOT switch selected; button unfinished

**Confirmed:** Bill accepted XUNPU `TS-1088R-02026`, JLCPCB/LCSC `C455280`,
and explicitly requested documenting that the button is still unfinished.
This supersedes the TE `3-1437565-0` / `C86463` selection above. The
two-terminal switch was proposed to simplify the connection: one terminal
to CN1-93 (`nRPIBOOT`), the other to GND, using the CM5's internal pull-up.
JLCPCB lists a 3.9 x 2.93 mm body, 2 mm height, 2.6 N force, 50 mA / 12 V
rating, 100,000 cycles, and Extended classification.

**Open:** exact datasheet and symbol/footprint verification, schematic
wiring and test point, PCB ECO, accessible placement/routing, and normal
boot/USB recovery testing. No Altium changes were made in this documentation
update. Updated the current design, boot subsystem note, and task dashboard.

Source: [JLCPCB C455280](https://jlcpcb.com/partdetail/Xunpu-TS_1088R02026/C455280).

## 2026-09-28 — Current BoM, footprint, and documentation reconciliation

**Confirmed from saved CAD:** The four active schematic sheets contain 43
placed components, and the saved PCB contains the same 43 designators, part
references, unique IDs, and footprint names. The LiveBOM has 29 matching
catalog items, representing 28 distinct LCSC codes because
CN1 and CN2 share one connector part. All referenced local footprint patterns
exist. The older 42-component/27-code review is a historical snapshot. The
current unresolved findings were consolidated into `documentation.md` and the
affected subsystem records.

**Open findings:** CN3 uses selected UMAX `91302-42-067RDM`/`C601195` with a
PCB footprint and model named `91302-32-067RDM`; manufacturer mechanical
comparison remains a release blocker. All 29 stored catalog statuses are
`Unknown` with empty part-choice groups; a purchasing BoM is still needed.
U5's MP2329 part uses an MP2384-named QFN footprint;
the two manufacturer datasheets show the same package class and pin functions,
but land dimensions need confirmation. No component substitution or CAD fix
was made.

**LiveBOM refresh observed during this review:** A separate 2026-09-28 save
filled the previously absent LCSC `Name` parameters for U1, U3, and CN3,
filled `Source=LCSC` for U1 and CN3, and synchronized CN3's Comment. The
latest saved `Name`, `Source`, `Value`, `Comment`, and `Footprint` parameters
now match the schematic placements. This documentation update did not edit
the LiveBOM or its history archive.

**Superseded status details:** The selected recovery switch is now `SW` in
the schematic and PCB. The 2026-09-23 PCB ECO joins `CN1-93` to `SW-1` and
grounds `SW-2`; the earlier statement that recovery control was absent is no
longer current. Access, test-point provision, and functional recovery remain
unverified. The Hailo TPS54302 buck is now `U1` (formerly `U3`); the camera
AP2112 LDO is now `U3` (formerly `U7`). The 2026-09-24 ECO retains the
camera LDO's incorrect pad connections, so its critical correction remains
open. The two current USB-C designators are `USBC 1` and `USBC2`; earlier
ground findings need a current-designator pad-net check.

## 2026-09-28 — Camera documentation reconciled

**Verified current decision:** use the standard Raspberry Pi Camera Module 3
with the IMX708 sensor, not Camera Module 3 Wide. This supersedes references
to an undecided or Arducam-class camera. The normal 22-to-15-pin Raspberry Pi
camera cable uses two CSI-2 data lanes; the carrier retains the complete
four-lane 22-pin interface, subject to cable contact-orientation and PCB
routing verification.

The official [CM5 datasheet](https://datasheets.raspberrypi.com/cm5/cm5-datasheet.pdf)
specifies internal 1.8 kΩ pull-ups to `CM5_3.3V` on
pin 80 `SCL0` and pin 82 `SDA0`. Do not populate another external pull-up pair
by default. Add external pull-ups only if later module documentation or
measurement establishes a specific need.

**Still incomplete:** the AP2112 camera regulator is `U3`, and its saved
physical pins 2–5 are incorrectly connected. Its intended VOUT capacitor is
also missing. Correct U3 and add the output capacitor before treating camera
power as complete. CSI signal wiring is drawn, but camera completion also
requires verification of the selected cable orientation, connector pad 1,
module clearance, current and thermal margin, PCB differential-pair rules,
routing, and functional testing.

## 2026-09-28 — Differential-pair impedance requirements verified

**Confirmed from the current official CM5 datasheet:** the carrier has nine
routed differential pairs in two impedance classes. PCIe lane 0 TX, PCIe lane
0 RX, and PCIe reference clock are 90 ohms differential. MIPI0 data lanes 0-3
and MIPI0 clock are 100 ohms differential. The programming USB 2.0 D+/D- pair
is 90 ohms differential, and its polarity must not be swapped. The earlier
85-ohm PCIe value in the project documentation is superseded by the current
CM5 component-specific guidance.

The Hailo-8L M.2 module datasheet identifies PET/PER and REFCLK as PCIe
differential signals and defers to the PCIe M.2 specification; it gives no
conflicting routing value. CM5 includes AC-coupling capacitors on its PCIe TX
signals, while the M.2 module supplies transmitter-side coupling in the other
direction. Do not duplicate these capacitors or add parallel termination
resistors without a reviewed device-specific requirement.

The selected Hirose `FH55-22S-0.5SH` is an impedance-controlled high-speed
GSSG connector. Its catalog characterizes the connector/FPC interconnect near
90 ohms with a broad tolerance, but this fixed connector behavior does not
change the CM5-mandated 100-ohm target for the carrier's MIPI PCB traces. The
USB-C connector drawing provides no separate routing target, so CM5's 90-ohm
USB requirement governs.

**CAD status:** the saved PCB contains no differential-pair objects. Its
generic 15 mil width/10 mil gap differential rule is a placeholder and is not
an approved geometry. Create separate PCIe, MIPI, and USB pair classes/rules,
then obtain actual widths and gaps from the final JLCPCB stackup. No schematic,
PCB, or library change was made during this documentation update.

Sources: current official
[CM5 datasheet](https://datasheets.raspberrypi.com/cm5/cm5-datasheet.pdf),
local Hailo-8L M.2 Module Data Sheet Rev. 4.0, and the Hirose FH55/FH55M
series catalog stored with the project.

## 2026-09-28 — PCB layout setup and saved-CAD reconciliation

Bill supplied `Project_Watchdog_PCB_Layout_Notes_2026-09-28.md` as the layout
session record. The approximately 100 mm x 60 mm working board outline is in
place. The saved board outline measures approximately that size, and all 43
components are currently top-side and inside the outline. This is placement
progress, not mechanical sign-off: mounting, connector-edge alignment, CM5 and
M.2 retention, camera cable access, antenna/heatsink keepouts, cooling, and a
1:1 fit check remain open.

**Confirmed saved setup:** the four copper layers are L1 `SIG 1`, L2 internal
`GND`, L3 internal `PWR`, and L4 `SIG 2`. The saved general rules are 0.15 mm
clearance, 0.20 mm minimum/0.25 mm preferred trace width, and 0.60 mm diameter
with 0.30 mm hole for through vias. The saved general-width maximum is 0.50 mm,
not the 1.0 mm reported in the external layout note; reconcile the intended
maximum in Altium. These generic rules do not replace current-based power-net
rules or controlled-impedance geometry.

**Reported plane and impedance setup:** the layout note records continuous L2
ground and L3 main-5-V planes, with CSI 100-ohm and USB/PCIe 90-ohm profiles
calculated from the layer stack. High-speed pairs are intended for L1 over the
uninterrupted L2 ground plane. L4 should be avoided for those pairs where
practical because its adjacent reference is the L3 power plane. Calculated
widths and gaps still require JLCPCB manufacturability confirmation.

**Saved-CAD discrepancies that must be resolved before routing:** the current
PCB net table still contains `NetC2_1`, not the reported renamed `5V` net, while
the schematic and documentation use `5V_MAIN`/`5V_6.5A`. Verify and save the
L2/L3 plane assignments and choose one authoritative main-rail name that will
survive the next ECO. The PCB contains zero differential-pair objects. The
reported CSI pair class has no saved members, and the enabled differential
routing rule remains the generic 15 mil width/10 mil gap rule rather than a
profile-linked rule. Define all nine pairs, populate the PCIe/MIPI/USB classes,
link their routing rules to the verified impedance profiles, save, and inspect
the serialized result before routing.

**Routing order:** route each converter and its input/output decoupling and
switching loops first; then CSI, PCIe, USB, and other sensitive controls;
follow with normal signals, power distribution, ground vias/stitching,
silkscreen cleanup, final DRC/return-path review, and manufacturing outputs.
Mechanical-layer graphics are reference geometry rather than copper or
silkscreen. Top Overlay is actual silkscreen and must be checked for pad and
component interference.

**DRC caution:** the layout notes report stale/corrupt-instance DRC behavior
from imported footprints that appeared to clear after affected placed
instances were replaced. Treat replacement as a workaround, not proof of
closure; watch for recurrence and require a clean final DRC after all ECOs and
routing. No PCB or schematic edit was made during this documentation update.

## 2026-09-29 — CM5 connector component and footprint verification closed

**Verified from the saved Altium libraries and placed design:** `CN1` and
`CN2` are both Amphenol `10164227-1001A1RLF`, LCSC `C6782225`. Each schematic
symbol has exactly 100 unique physical pin designators `1–100`, passive pin
types, and the correct linked PCB model
`CONN-SMD_100P-P0.40_10164227-1001A1RLF`. The saved PCB contains two instances
of that footprint, one for each connector.

**Manufacturer land-pattern comparison:** the footprint contains 100 SMT pads
at 0.40 mm pitch. The contact lands are 0.20 mm x 0.70 mm, the contact span is
19.60 mm, and the two row centers are 3.08 mm apart, producing the specified
3.78 mm total pad-row extent. The part has no hold-down holes, consistent with
the exact `-1001A1RLF` no-hold-down variant and its standard 1.5 mm CM5 mated
stack height.

**Decision:** connector component verification is closed. The symbols,
footprint, and part identity match; no replacement, redraw, or library change
is required. Both placed instances are approved for routing. Final CM5
alignment, orientation, surrounding clearance, retention, and 1:1 assembly fit
remain board-level placement checks and do not reopen the component selection.
No schematic, PCB, or library file was changed during this verification.

Sources: current official Raspberry Pi CM5 datasheet, official Amphenol
`10164227` product drawing, and the saved project SchLib/PcbLib/SchDoc/PcbDoc
records.

## 2026-10-05 — Routing sprint priorities and finish targets

Bill set the immediate PCB-layout priority: finish the many high-speed
differential pairs before ordinary routing, target completion of all routing
by 2026-10-06, and use the following work session for final cleanup and
checks. Completing routing and final checks together on 2026-10-06 is a
stretch goal rather than a release commitment.

The routing task includes a placement pass. Components may need local
adjustment for clean fanout, short critical paths, uninterrupted return paths,
decoupling, connector and cable access, and mechanical clearance. Placement
must be reviewed again after routing rather than accepted only because every
component lies inside the outline.

A read-only inspection of the saved `Watchdog PCB.PcbDoc` dated 2026-10-05
found `DifferentialPairs6/Header = 0`: there are currently no serialized
differential-pair objects. Therefore the first routing action is to create and
verify the nine PCIe/MIPI/USB pair objects and their classes, impedance-linked
rules, and skew constraints, followed immediately by routing those pairs. The
final phase requires iterative and final DRC, an unrouted-connection check,
plane re-pour and return-path review, placement/mechanical and silkscreen
review, ERC/ECO consistency, and manufacturing-output review. This entry
records the work plan and saved pair-object count; it does not declare routing,
placement, or DRC complete.

## 2026-10-09 - Independent saved PCB routing audit

Routing is substantially implemented in the saved PCB: all nine differential
pairs are defined and each member has top-layer tracks. Finish corner GND
vias, revise the board outline, and add/re-pour the required polygon copper.
Then refresh connectivity and resolve remaining DRC items in Altium. Final
routing, impedance, and release sign-off remain open.

The read-only saved-file audit found 85 connection records (83 GND and two
`NetCN1_78`), a broadly scoped 90-ohm differential rule, and unequal USB
track-only lengths. No DRC report was found, so a small remaining violation
count is not independently confirmed. See the [PCB audit](PCB-Audit-2026-10-09.md) for evidence
and the limits of this inspection.

Inspected the October 8 saved PCB, hash and detailed findings recorded in the
audit. This supersedes the October 5 no-pair-object/routing-start checkpoint.
Confirmed nine pair objects, routed top-layer pair tracks, 105 vias (57 GND),
two internal split-plane records, and a rectangular approximately 100 x 60 mm
outline. Corner GND vias remain absent near the outline corners. Saved
connectivity and rule-scope findings require Altium review; no fresh DRC or
electrical sign-off is claimed. Earlier electrical findings remain historical
checks pending re-verification. Documentation only was changed in this pass.

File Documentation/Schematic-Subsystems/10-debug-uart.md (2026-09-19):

# 10 — Debug UART

Last updated: 2026-09-19

## Purpose

Provide a simple, independent serial-console path for observing CM5 bootloader,
kernel, and early userspace messages when USB software, Wi-Fi, or SSH is not
working.

## Current status

**Schematic complete and transferred to PCB.** The CM5 pins are routed to the
three-pin JST debug connector with TX, RX, and GND. The interface remains
3.3 V logic only.

## Confirmed design

- CM5 pin 55 `GPIO14/UART0_TX` connects to `DEBUG_UART_TX`.
- CM5 pin 51 `GPIO15/UART0_RX` connects to `DEBUG_UART_RX`.
- Interface: TX, RX, and GND on an accessible three-pin connector.
- Board connector: JST GH `SM03B-GHS-TB`, JLCPCB/LCSC `C514175`.
- Logic level: 3.3 V only.
- External adapter: a USB-to-UART adapter configured for 3.3 V signaling.
- The adapter's RX connects to carrier TX; adapter TX connects to carrier RX;
  grounds connect together.
- The UART header must not be used to power the carrier board.
- Recorded terminal format: 115200 baud, 8 data bits, no parity, 1 stop bit
  (`115200 8N1`).
- UART is for diagnosis; it does not replace USB eMMC flashing.

## Planned schematic content

- Three-pin connector with unmistakable TX, RX, and GND labels.
- Test points on UART signals if they do not reduce connector clarity.
- Pin-order marking suitable for silkscreen documentation later.

## Practical use

1. Power the carrier board normally.
2. Configure the USB-to-UART adapter for 3.3 V.
3. Connect adapter RX to carrier TX, adapter TX to carrier RX, and GND to GND.
4. Open the adapter's COM port at `115200 8N1`.
5. Power-cycle or reset the CM5 and capture all output from the beginning.

UART output can distinguish several failure classes: no power/no execution,
bootloader failure, missing boot files, kernel failure, Device Tree problems,
and userspace/service failures.

## Definition of done

- TX/RX direction is checked from both the CM5 and adapter perspectives.
- The connector pin order and voltage level are documented.
- The connector remains three-pin TX/RX/GND; no power pin is added.
- The signals are not connected to 5 V.
- The Linux image plan enables the appropriate serial console.
- The header remains physically accessible with the assembled CM5 installed.

## References

- `Documentation/Research MD/programming.md`.
- `Documentation/Research MD/I2C-UART-Explainer.md`.
- `Documentation/Research MD/CM5-Connector-Wiring-and-Bringup.md`.

## Session notes

- 2026-09-18: Initial UART draft created with operator-level connection and
  troubleshooting guidance.
- 2026-09-19: Completed the JST GH UART interface and transferred it to the
  PCB document. Accessibility and silkscreen pin labeling remain layout tasks.

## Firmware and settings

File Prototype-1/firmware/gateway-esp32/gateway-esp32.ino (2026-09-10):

#include <WiFi.h>
#include <WiFiMulti.h>
#include <WiFiUdp.h>
#include <RCSwitch.h>
#include "secrets.h"

WiFiMulti wifiMulti;
const int udpPort = 5005;

WiFiUDP udp;
RCSwitch mySwitch = RCSwitch();

void setup() {
  Serial.begin(115200);

  // Connect to Wi-Fi
  // Register all known networks, then connect to whichever is in range
  for (int i = 0; i < wifiCredCount; i++) {
    wifiMulti.addAP(wifiCreds[i].ssid, wifiCreds[i].password);
  }
  while (wifiMulti.run() != WL_CONNECTED) {
    delay(500);
    Serial.print(".");
  }
  
  Serial.println("\nWiFi connected");
  Serial.print("ESP32 IP address: ");
  Serial.println(WiFi.localIP());

  // Start UDP listener
  udp.begin(udpPort);
  Serial.printf("Listening for UDP packets on port %d\n", udpPort);

  // Setup 433 MHz transmitter
  mySwitch.enableTransmit(12);   // GPIO 12 connected to TX module DATA
  mySwitch.setPulseLength(350);
  mySwitch.setRepeatTransmit(10);
}

void loop() {
  int packetSize = udp.parsePacket();
  if (packetSize) {
    char buf[255];
    int len = udp.read(buf, 255);
    if (len > 0) buf[len] = '\0';

    String msg = String(buf);
    Serial.println("Received: " + msg);

    if (msg.startsWith("DETECTED:")) {
      if (msg.indexOf("dog") > 0) {
        Serial.println("Sending RF code for dog");
        mySwitch.send(11111, 24);
      }
      else if (msg.indexOf("cat") > 0) {
        Serial.println("Sending RF code for cat");
        mySwitch.send(22222, 24);
      }
      else {
        Serial.println("Sending RF code default");
        mySwitch.send(12345, 24);
      }
    }
  }
}

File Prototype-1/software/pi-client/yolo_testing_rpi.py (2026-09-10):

#!/usr/bin/env python3
"""
Raspberry Pi client: captures frames from Picamera2, JPEG-encodes them, and sends to PC via imageZMQ.
Prints server reply (b"DETECTED" or b"OK" or other things)

Usage:
  python3 pi_client_sender.py --server-ip 192.168.1.100 --port 5555 --size 640x480 --quality 85
"""
import argparse
import socket
import time
import cv2
import numpy as np
import imagezmq

try:
    from picamera2 import Picamera2
    PICAMERA_AVAILABLE = True
except Exception:
    PICAMERA_AVAILABLE = False

def parse_args():
    p = argparse.ArgumentParser()
    p.add_argument("--server-ip", type=str, required=True, help="PC server IP address")
    p.add_argument("--port", type=int, default=5555, help="PC server port")
    p.add_argument("--size", type=str, default="640x480", help="frame size WxH, e.g. 640x480 or 800x600")
    p.add_argument("--quality", type=int, default=85, help="JPEG quality (0-100)")
    p.add_argument("--fps", type=int, default=0, help="Optional FPS cap; 0 for uncapped (server throttles)")
    p.add_argument("--testcam", action="store_true", help="Use synthetic frames if Picamera2 not available")
    return p.parse_args()

def init_camera(size_wh):
    if not PICAMERA_AVAILABLE:
        return None
    from picamera2 import Picamera2
    picam2 = Picamera2()
    w, h = size_wh
    config = picam2.create_preview_configuration(main={"format":"XRGB8888", "size": (w, h)})
    picam2.configure(config)
    picam2.start()
    time.sleep(1.0)  # warmup
    return picam2

def get_frame(picam2, size_wh, counter):
    if picam2 is not None:
        return picam2.capture_array()
    # Fallback synthetic frame (e.g., when testing on a laptop without camera)
    w, h = size_wh
    img = np.zeros((h, w, 3), dtype=np.uint8)
    cv2.putText(img, f"TEST FRAME {counter}", (10, 40), cv2.FONT_HERSHEY_SIMPLEX, 1.0, (255,255,255), 2, cv2.LINE_AA)
    return img

def main():
    args = parse_args()
    w, h = map(int, args.size.lower().split("x"))
    size_wh = (w, h)

    sender = imagezmq.ImageSender(connect_to=f"tcp://{args.server_ip}:{args.port}", REQ_REP=True)
    rpi_name = socket.gethostname()
    if not isinstance(rpi_name, str):
        rpi_name = str(rpi_name)

    picam2 = None
    if PICAMERA_AVAILABLE and not args.testcam:
        try:
            picam2 = init_camera(size_wh)
        except Exception as e:
            print(f"[Pi] Picamera2 init failed, falling back to synthetic frames: {e}")
            picam2 = None
    else:
        if not PICAMERA_AVAILABLE:
            print("[Pi] Picamera2 is not available. Using synthetic frames (--testcam).")
        else:
            print("[Pi] Using synthetic frames (--testcam).")

    encode_params = [int(cv2.IMWRITE_JPEG_QUALITY), int(args.quality)]
    print(f"[Pi] Streaming to tcp://{args.server_ip}:{args.port} at {w}x{h}, JPEG q={args.quality}")
    if args.fps > 0:
        print(f"[Pi] FPS capped at ~{args.fps}")

    try:
        counter = 0
        next_time = time.time()
        frame_interval = (1.0 / args.fps) if args.fps > 0 else 0.0

        while True:
            frame = get_frame(picam2, size_wh, counter)
            # Encode as JPEG
            ok, jpg = cv2.imencode(".jpg", frame, encode_params)
            if not ok:
                print("[Pi] JPEG encode failed; skipping frame")
                continue
            reply = sender.send_jpg(rpi_name, jpg)

            # Handle server reply
            if reply == b"DETECTED":
                print(f":[PI] Frame {counter}: DeTECTED")
            elif reply == b"OK":
                if counter % 30 == 0:
                # Print occasionally to show liveness
                    print(f"[PI] Frame {counter}: OK")
            else:
                print(f"[PI] Frame {counter}: Unknown reply: {reply}")

            counter += 1

            # Optional FPS cap
            if frame_interval > 0:
                next_time += frame_interval
                sleep_for = next_time - time.time()
                if sleep_for > 0:
                    time.sleep(sleep_for)
                else:
                    next_time = time.time()
    finally:
        try:
            if picam2 is not None:
                picam2.stop()
        except Exception:
            pass

if __name__ == "__main__":
    main()

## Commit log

2026-08-02 Initial commit: Watchdog CM5 carrier board documentation
    Project docs, journal, datasheets, and research notes for the CM5
    carrier board build. Obsidian vault config, canvas graphics, and
    local agent settings excluded ? this repo is for documenting the
    project journey, not the vault itself.
2026-08-02 Add Session 4 notes (2026-08-01) and simplify language across all docs
    Folded in today's timeline extension, assembly plan reversal, and
    GitHub sync-gap findings from CLAUDE.md/Journal.md. Rewrote all six
    markdown files in plainer language for a junior-engineering-student
    reading level - same facts and part numbers, simpler wording and
    spelled-out jargon.
2026-08-09 Pick input-protection parts (TVS, eFuse, backup fuse), fix stage ordering
    Closes the input-protection stage: SMBJ12A (TVS), TPS25947 (eFuse),
    1206T3A63V (backup fuse) - all confirmed with LCSC part numbers. Also
    corrects the protection topology from TVS->fuse->eFuse to
    fuse->TVS->eFuse so the fuse backs up a shorted TVS, not just a shorted
    eFuse.
2026-08-09 Confirm no protection-chain parts are JLCPCB Basic; flag stock risk
    Checked SMBJ12A/TPS25947/1206T3A63V plus the whole existing power chain
    against JLCPCB's live parts library - all Extended, none Basic. Also
    surfaces a stock risk found while checking: TPS25947 and TPS22965 exact
    reels have dropped to very low unit counts since being picked.
2026-08-09 Add datasheets for input-protection parts (TVS, eFuse, backup fuse)
    SMBJ12A (C151251), TPS25947 (C3662799), 1206T3A63V (C354897) - the
    three parts picked for the fuse -> TVS -> eFuse protection stage.
2026-08-09 Add Altium project files (Project Watchdog schematic + libraries)
    Mirrors the local Altium project folder so the design can be resumed
    from another machine - schematic, .PrjPcb, and component libraries.
    Excludes Altium's auto-generated History/ and __Previews/ folders via
    .gitignore since they're redundant with git history / regenerated
    locally on open.
    [C165948.PcbLib, C165948.SchLib, P1.SCHLIB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]
2026-08-09 Flatten Altium/Project Watchdog into Altium directly
    [C165948.PcbLib, C165948.SchLib, P1.SCHLIB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]
2026-08-09 Pick USB-C connector (TYPE-C-31-M-12, LCSC C165948)
    Confirmed the part against the design's needs: CC1/CC2 for PD negotiation,
    VBUS/GND, USB 2.0 data pairs, 5A/20V rating with margin at the 9V/~13W
    budget. Confirmed through-hole mounting legs, feeding into the open
    JLCPCB through-hole assembly question alongside the DF40 and M.2 socket.
2026-08-10 Remove Altium project copy from documentation repository
    [C165948.PcbLib, C165948.SchLib, P1.SCHLIB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]
2026-08-10 Document main power and USB-C schematic decisions
2026-08-16 Document programming plan and current power datasheets
2026-09-04 Document CM5 connector wiring and bring-up plan
    # Conflicts:
    # Documentation/Journal.md
    # Documentation/documentation.md
2026-09-07 Document CM5 connector pin assignments
2026-09-07 Add CM5 connector release blocker notice
2026-09-07 Add Altium hardware design assets
    [5V Buck Converter.SchDoc, Amphenol ICC_1.SchDoc, Amphenol ICC_2.SchDoc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]
2026-09-08 Sync latest Altium project files
    [C6782225_Part 1.SchLib, Project Watchdog.PrjPcb]
2026-09-09 Document M.2 and local power design
    [Buck to M.2 & CSI.SchDoc, C601195.SchLib]
2026-09-10 Organize Prototype 1 files and update Altium project
    [Project Watchdog.PrjPcb]
2026-09-18 Update power rails and interface schematics
    [5V Buck Converter.SchDoc, Amphenol ICC_1.SchDoc, Amphenol ICC_2.SchDoc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]
2026-09-19 Complete Hailo and camera interface schematics
    [Amphenol ICC.SchDoc, Amphenol ICC_1.SchDoc, Amphenol ICC_2.SchDoc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]
2026-09-19 Synchronize renamed Altium project sheets
    [Project Watchdog.PrjPcb]
2026-09-19 Refresh schematic resume documentation
2026-09-19 Complete schematic and begin PCB layout
    [Amphenol ICC.SchDoc, C12447.SchLib, C19268642.SchLib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]
2026-09-20 Record schematic review issues and proposed Basic substitutions
2026-09-24 Update carrier board CAD and hardware review documentation
    [Amphenol ICC.SchDoc, C165948.step, C311983.SchLib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]
2026-09-25 Add BOM document to Altium project and save project history
    [Project Watchdog.PrjPcb]
2026-09-28 Consolidate project documentation and reconcile BOM status
2026-09-29 Update PCB layout and differential-pair documentation
    [Amphenol ICC.SchDoc, C42459160.PcbLib, C723484.PcbLib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]
2026-10-04 Update USB-C protection and PCB design files
    [C601195.PcbLib, Project Watchdog.PrjPcb, USBC_Protection.SchDoc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]
2026-10-04 Update Watchdog PCB layout and design history
    [Watchdog PCB.PcbDoc]
2026-10-05 Update PCB layout, footprints, and routing plan
    [Amphenol ICC.SchDoc, C15849.PcbLib, C311983.PcbLib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]
2026-10-09 Save current Watchdog schematics, PCB layout, and design history
    [Amphenol ICC.SchDoc, M.2 & CSI2.SchDoc, Watchdog PCB.PcbDoc]
2026-10-09 Document verified PCB routing progress and remaining finishing checks
2026-10-14 Update carrier board project, USB-C protection, and PCB layout
2026-10-16 Update carrier board design, component sourcing, and fabrication outputs
    Refresh schematics, PCB layout, libraries, design history, and release documentation. Include current fabrication exports and BOM, and remove the legacy Prototype-1 files.
